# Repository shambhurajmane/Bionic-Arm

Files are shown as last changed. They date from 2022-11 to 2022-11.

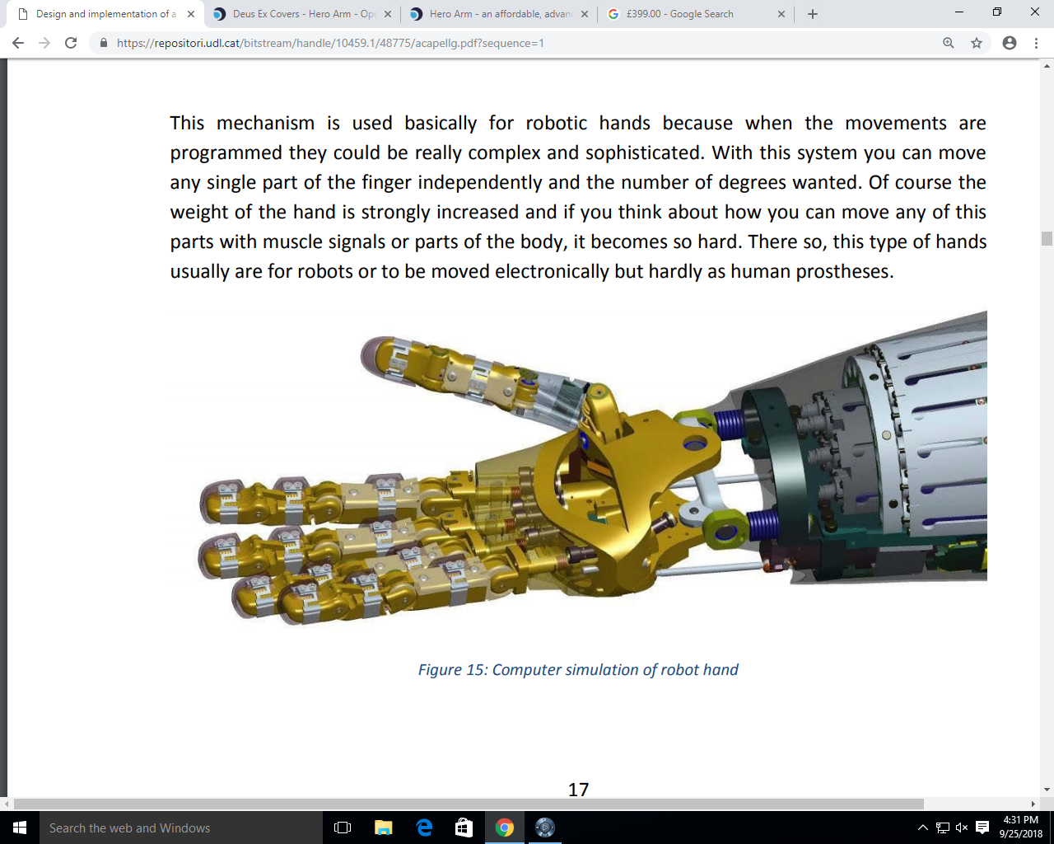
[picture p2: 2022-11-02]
Reference Doc/ARM1.png

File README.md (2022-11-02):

# Build and Control a Bionic Arm Using EMG Signals 

Brainwaves are the signals used by the human brain to communicate with the body. Most of the bionic arms designed and used in India are very costly yet they fail to provide the high Degree of Freedom. 
Due to less DOF, the movements of the arm are restricted to only a few actions like gripping. 

##  Objective of project 

-  To study the human-arm anatomy with reference to different gestures.
- To study the EMG signals related to lower arm/finger gestures.
- To acquire the EMG signals from a healthy person (one subject) and create datasets for various pre-decided gestures.
- To analyse the recorded signals and extract various features from them.
- To create a machine learning model that can identify these features.
- To apply the output of the machine learning model to the actuators in Bionic Arm to actuate the gestures.
- To design a low cost, high functionality (high Degrees of Freedom) Bionic Arm.
- To design a lightweight Bionic Arm using 3D print technology. 

We have succesfully built the Bionic Arm with 14 DOF.

git1

## Features

- Input:  EMG signal controlled bionic arm.
- 14 DoF bionic arm.
- Max weight is 656 gm for this we have used 3D printing technology.
- Fullscreen mode
- Machine learning model for classification of grasps.
- Total Power dissipated: 8W
- No of Hours the 2200mAh battery will last=(12*2200mAh)/8 W=3.3 hours.

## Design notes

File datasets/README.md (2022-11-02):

- The machine learning model is built to classify the gestures such as pinch , fist and relax.
- The dataset required for training and testing purpose was drawn from three EMG-sensors.
- These sensors are used to collect the data from three different regions of forearm.
- Sets of signal readings from three sensors are assigned to 'X' variable and gesture labbel is assigned to 'Y' variable.Then data was used for training and testing by the algorithm .The training dataset and testing dataset was in the ratio of 3:1.Accuracy of different classifiers such as KN Neighbours,Decision Tree,LINEAR DISCRIMINATION ANALYSIS, GAUSSIAN NB,LOGISTIC REGRESSION were tested against the dataset.Higher accuracy was obtained with Decision Tree.

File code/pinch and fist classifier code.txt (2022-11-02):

import pandas as pd
import matplotlib.pyplot as plt
import sklearn
from sklearn.model_selection import train_test_split
from sklearn import linear_model
from sklearn.utils import shuffle
from sklearn import preprocessing
import numpy as np

# PRE-PROCESSING OF DATA
file = pd.read_table('pinch and fist 8 december.txt')
feature_names = ['Sensor1', 'Sensor2', 'Sensor3']
X = file[feature_names]
y = file['grasp']

# remove nan error
import pandas as pd
X=X.replace([np.inf,-np.inf])
X = X.apply (pd.to_numeric, errors='coerce')
X = X.dropna()

y=y.replace([np.inf,-np.inf])
y = y.apply (pd.to_numeric, errors='coerce')
y = y.dropna()

# TESTING AND TRAINING
X_train, X_test, y_train, y_test = train_test_split(X, y, random_state=5)
from sklearn.preprocessing import MinMaxScaler
scaler = MinMaxScaler()
X_train = scaler.fit_transform(X_train)
X_test = scaler.transform(X_test)

# LOGISTIC REGRESSION
from sklearn.linear_model import LogisticRegression
logreg = LogisticRegression()
logreg.fit(X_train, y_train)
print('Accuracy of Logistic regression classifier on training set: {:.2f}'
     .format(logreg.score(X_train, y_train)))
print('Accuracy of Logistic regression classifier on test set: {:.2f}'
     .format(logreg.score(X_test, y_test)))

# DECISION TREE
from sklearn.tree import DecisionTreeClassifier
clf = DecisionTreeClassifier().fit(X_train, y_train)
print('Accuracy of Decision Tree classifier on training set: {:.2f}'
     .format(clf.score(X_train, y_train)))
print('Accuracy of Decision Tree classifier on test set: {:.2f}'
     .format(clf.score(X_test, y_test)))

# KN NEIGHBORS
from sklearn.neighbors import KNeighborsClassifier
knn = KNeighborsClassifier()
knn.fit(X_train, y_train)
print('Accuracy of K-NN classifier on training set: {:.2f}'
     .format(knn.score(X_train, y_train)))
print('Accuracy of K-NN classifier on test set: {:.2f}'
     .format(knn.score(X_test, y_test)))

#LINEAR DISCRIMINATION ANALYSIS
from sklearn.discriminant_analysis import LinearDiscriminantAnalysis
lda = LinearDiscriminantAnalysis()
lda.fit(X_train, y_train)
print('Accuracy of LDA classifier on training set: {:.2f}'
     .format(lda.score(X_train, y_train)))
print('Accuracy of LDA classifier on test set: {:.2f}'
     .format(lda.score(X_test, y_test)))

# GAUSSIAN NB
from sklearn.naive_bayes import GaussianNB
gnb = GaussianNB()
gnb.fit(X_train, y_train)
print('Accuracy of GNB classifier on training set: {:.2f}'
     .format(gnb.score(X_train, y_train)))
print('Accuracy of GNB classifier on test set: {:.2f}'
     .format(gnb.score(X_test, y_test)))

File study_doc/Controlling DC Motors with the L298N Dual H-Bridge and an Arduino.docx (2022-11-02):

Literature review

Development Boards

Development board is basically a printed circuit board with circuitry and hardware on-board to facilitate experimentation with certain microcontrollers. These boards can save you from a lot of repetitive tasks.

1. Arduino Development Board: ...
2. Raspberry Pi Development Board: ...
3. The BeagleBone Black Development Board: ...
4. The Intel Galileo Development Board: ...
5. The pcDuino Development Board:
6. The Uruk Development Board: ...
7. The Goldilocks Development Board: ...
8. The ExtraCore Development Board:
9. DIY Printed Circuit (PCB) Boards:

Arduino Development Board:

Arduino is the popular open-source electronics prototyping stage focused around simple to-utilize equipment and software. It's proposed for specialists, designers, and anybody intrigued by making intelligent articles or situations and is intended to be as adaptable as would be prudent to fit your venture's necessities. The Arduino Development Board is a good example of top development boards for DIY projects. Arduino is a company that deals with open source computer hard ware and software. The company designs and does manufacturing of kits creating digital devices and many interactive objects which have the capability of sensing and making good control of the whole physical world. Since it is an example of a microcontroller, it works swiftly and steadily. It is manufactured primarily by Smart Projects in Italy and many other countries and vendors.

# ARDUINO MEGA 2560 REV3

The MEGA 2560 is designed for more complex projects. With 54 digital I/O pins, 16 analog inputs and a larger space for your sketch it is the recommended board for 3D printers and robotics projects. This gives your projects plenty of room and opportunities.

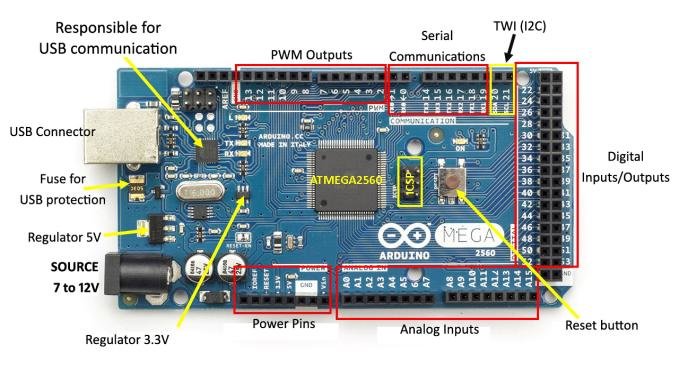
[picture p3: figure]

Controlling of servo actuation

### H-Bridge

Now that you know how DC motors work, how you can reverse their direction by changing polarity and how you can change their speed using pulse width modulation, let’s examine an easy way to do this using a very common circuit configuration called an “H-Bridge”.

An “H-Bridge” is simply an arrangement of switching the polarity of the voltage applied to a DC motor, thus controlling its direction of rotation. To visualize how this all works I’ll use some switches, although in real life an H-Bridge is usually built using transistors. Using transistors also allows you to control the motor speed with PWM, as described above.

In the first diagram we can see four switches which are all in the open or “off” position. In the center of the circuit is a DC motor. If you look at the circuit as it is drawn here you can distinctly see a letter “H”, with the motor attached in the center or “bridge” section – thus the term “H-Bridge”.

If we close (i.e. turn on) two of the switches you can see how the voltage is applied to the motor, causing it to turn clockwise.

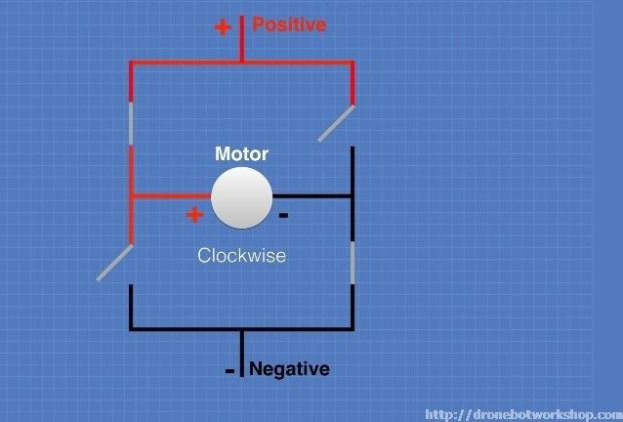
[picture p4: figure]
H-Bridge Clockwise
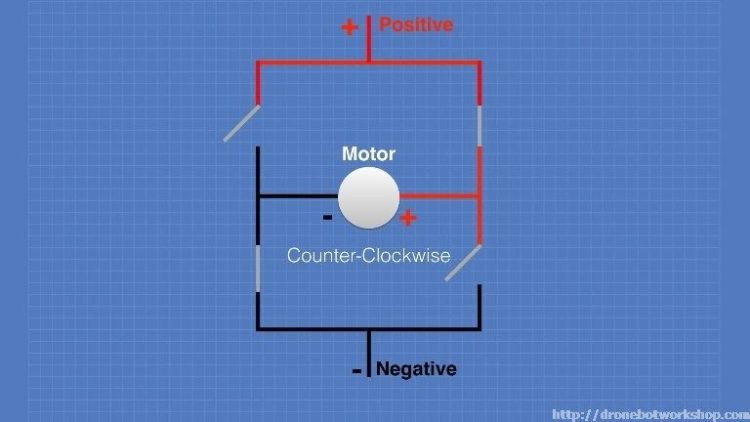
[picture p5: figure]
H-Bridge Counter-Clockwise
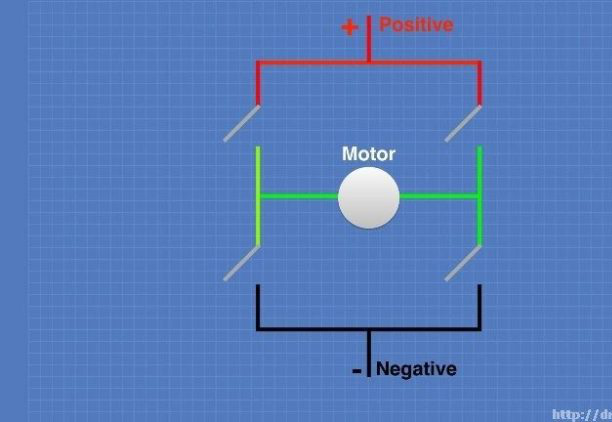
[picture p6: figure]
H-Bridge Configuration

Now we’ll open those switches and close the other two. As you can see this causes the polarity of the voltage applied to the motor to be reversed, resulting in our motor spinning counterclockwise.

This is pretty simple but effective. In fact if all you need to do is design a circuit to drive the motor full-speed in either direction you could actually build this as shown here, using a 4PDT (4 Pole Double-Throw) center-off switch. But of course we want to control the motor using an Arduino, so an electronic circuit where the switches are replaced by transistors is what we need.

### 1) L298N Module Pinouts

You’ll find a few different styles of L298N boards but they all operate in the same fashion. The board contains an L298N mounted on a heatsink, a 5 volt voltage regulator to “optionally) provide power for logic circuits, supporting diodes and capacitors and connectors as follows:

- Logic inputs for each H-Bridge circuit
- Power supply inputs for the motor power supply
- An optional 5 Volt power input for the logic circuits.
- Outputs for each DC motor

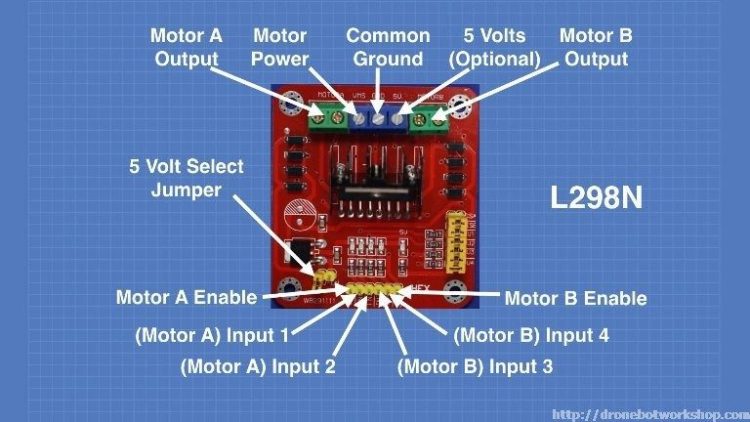
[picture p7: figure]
L298 Motor Control Module

A typical L298N Board is shown here.

You’ll notice that the board also has a number of jumpers. Most of the time you will leave them in place, with the exception of one. They are as follows:

- CSA – This is the “current sensing” function for Motor A. If the jumper is in this function is ignored. Most of the time you’ll leave this jumper in place.
- CSB – The “current sensing” function for Motor B. Again you’ll usually just leave this in place to disable this function.
- U1 – Input 1 pull-up resistor. You will usually leave this in place, which enables a 10k pull-up resistor for the input.
- U2 – Input 2 pull-up resistor.
- U3 – Input 3 pull-up resistor.
- U4 – Input 4 pull-up resistor.
- 5v-EN – This is the only jumper that you need to really pay attention to. When this jumper is in place it enables the boards internal 78M05 5 Volt regulator, supplying logic power from the motor power supply. When this jumper is enabled you will NOT supply 5 volts to the 5 Volt input terminal. When the jumper is removed you will need to supply 5 Volts to the 5 Volt input terminal.

If you do use the internal voltage regulator you’ll have to supply the motor power supply with at least 7.5 volts.

Speaking of the motor power supply it needs to be a bit higher voltage than the actual motor requirements. This is due to the internal voltage drop in the transistors that form the H-Bridge circuit. The combined voltage drop is 1.4 volts, so if you are using 6 Volt motors you’ll need to give the board 7.4 volts, if you have 12 volt motors then your motor supply voltage will need to be 13.4 volts.

The board has four input terminals plus two enable terminals. You will use these terminals to control both direction and speed or each motor. They are as follows:

- IN1 – Input 1 for Motor A
- IN2 – Input 2 for Motor A
- IN3 – Input 3 for Motor B
- IN4 – Input 4 for Motor B
- EN1 – Enable line for Motor A
- EN2 – Enable Line for Motor B

In order to simplify things a bit I’ll just discuss the inputs and enable for Motor A, Motor B functions identically.

The two Input lines control the direction that the motor rotates. I will call one direction “forward” and the other one “reverse”, if it makes more sense to you just substitute “clockwise” and “counterclockwise”.

You control motor direction by applying either a Logic 1 (5 Volts) or Logic 0 (Ground) to the inputs. This chart illustrates how this is done.

INPUT 1 | INPUT 2 | DIRECTION
Ground (0) | Ground (0) | Motor Off
5 Volts (1) | Ground (0) | Forward
Ground (0) | 5 Volts (1) | Reverse
5 Volts (1) | 5 Volts (1) | Not Used

As you can see only two combinations are actually used to control the direction of the motors rotation.

The Enable line can be used to turn the motor on, to turn it off and to control its speed. When the Enable line is at 5 Volts (1) the motor will be on. Grounding the Enable line (0) will turn the motor off.

To control the speed of the motor you apply a Pulse Width Modulation (PWM) signal to the Enable line. The shorter the pulse width, the slower the motor will spin.

2) MD10C

1.0 Introduction:

Enhanced 10Amp DC Motor Driver (MD10C) (http://cytron.com.my/p-md10c)is an enhanced version of the MD10B which is designed to drive high current brushed DC motor up to 13A continuously (for Rev2.0). It offers several enhancements over the MD10B such as support for both locked anti-phase and sign-magnitude PWM signal as well as using full solid state components which result in faster response time and eliminate the wear and tear of the mechanical relay.

Arduino main boards such as Arduino Uno (http://cytron.com.my/p-arduino-uno) are quite popular these days due to its easy-to-use programming environment. Therefore, by interfacing Arduino main board with MD10C, we gain easier control of DC motors. In addition, further adding an Arduino LCD Keypad Shield can help us to control the DC motor that connected to MD10C with the 6 momentary push buttons (built-in push buttons on LCD keypad shield including 1 Reset button) and also display some useful message or information.

In this tutorial, I am going to show several simple ways to drive DC brush motor using MD10C and Arduino.

How does MD10C work?

One of the features of MD10C is it supports both sign-magnitude and locked anti-phase PWM signal, means you can control motor in 2 different ways!

- Sign-magnitude mode You require 2 separate signals to control the motor, one is for direction (counterclockwise or clockwise) and another is for the speed. To control motor direction, DIR pin is connected to HIGH or LOW for different direction, whereas PWM pin is fed with PWM signal to control the motor speed.
- Locked anti-phase mode In this mode, only 1 signal is required to control both speed and direction of motor. PWM pin of MD10C is always connected to HIGH (5V), while DIR pin is fed with d to PWM signal. The direction of motor depends on whether the duty cycle of PWM signal is less than or more than 50%. The motor will run in one direction if the duty cycle is less than 50% and another direction if more than 50%. The motor stops if duty cycle is 50% (approximately). The speed depends on the percentage of duty cycle.

Sign-magnitude VS Locked anti-phase

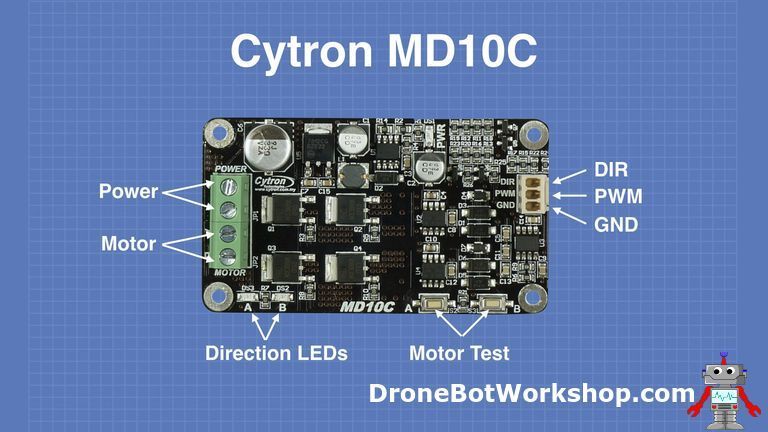
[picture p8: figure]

Main advantage of using locked anti-phase mode compare to sign-magnitude mode in motor controlling is it reduces number of I/O pins used since it uses only 1 signal for controlling both the speed and direction of motor. However, if locked anti-phase is used, in the beginning motor will run at maximum speed (as you can see in the video) when there is no PWM signal. Users will have to provide PWM signal at 50% duty cycle to DIR pin or set PWM pin (MD10C) to LOW state in the beginning. In terms of programming, the algorithm will be more complex because in locked anti-phase mode, motor speed changes with increment or decrement of PWM value depends on the direction which the motor is at. Motor becomes slower with increment of duty cycle if duty cycle of PWM signal is less than 50% or otherwise if duty cycle is more than 50%.

3) Md10a

Introduction

MDD10A (http://cytron.com.my/p-md10c) stands for Motor Driver Dual Channel 10(Amps). This DRIVER is the dual channel version of MD10C (http://cytron.com.my/p-md10c) which is designed to drive 2 brushed DC motors at high current s up to 10A each, continuously. Just like MD10C (http://cytron.com.my/p-md10c), MDD10A (http://cytron.com.my/p-md10c) also supports locked-antiphase and sign-magnitude PWM control. It uses all solid state components resulting in faster response times and eliminates the wear and tear of mechanical relays.

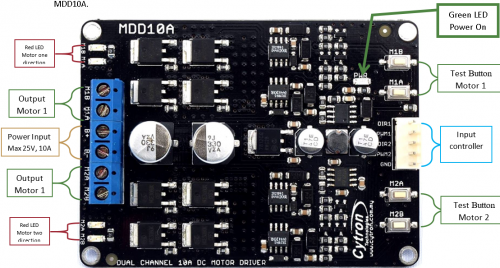
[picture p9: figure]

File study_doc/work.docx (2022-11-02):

work

### Why Arduino?

Thanks to its simple and accessible user experience, Arduino has been used in thousands of different projects and applications. The Arduino software is easy-to-use for beginners, yet flexible enough for advanced users. It runs on Mac, Windows, and Linux. Teachers and students use it to build low cost scientific instruments, to prove chemistry and physics principles, or to get started with programming and robotics. Designers and architects build interactive prototypes, musicians and artists use it for installations and to experiment with new musical instruments. Makers, of course, use it to build many of the projects exhibited at the Maker Faire, for example. Arduino is a key tool to learn new things. Anyone - children, hobbyists, artists, programmers - can start tinkering just following the step by step instructions of a kit, or sharing ideas online with other members of the Arduino community.

There are many other microcontrollers and microcontroller platforms available for physical computing. Parallax Basic Stamp, Netmedia's BX-24, Phidgets, MIT's Handyboard, and many others offer similar functionality. All of these tools take the messy details of microcontroller programming and wrap it up in an easy-to-use package. Arduino also simplifies the process of working with microcontrollers, but it offers some advantage for teachers, students, and interested amateurs over other systems:

- Inexpensive - Arduino boards are relatively inexpensive compared to other microcontroller platforms. The least expensive version of the Arduino module can be assembled by hand, and even the pre-assembled Arduino modules cost less than $50
- Cross-platform - The Arduino Software (IDE) runs on Windows, Macintosh OSX, and Linux operating systems. Most microcontroller systems are limited to Windows.
- Simple, clear programming environment - The Arduino Software (IDE) is easy-to-use for beginners, yet flexible enough for advanced users to take advantage of as well. For teachers, it's conveniently based on the Processing programming environment, so students learning to program in that environment will be familiar with how the Arduino IDE works.
- Open source and extensible software - The Arduino software is published as open source tools, available for extension by experienced programmers. The language can be expanded through C++ libraries, and people wanting to understand the technical details can make the leap from Arduino to the AVR C programming language on which it's based. Similarly, you can add AVR-C code directly into your Arduino programs if you want to.
- Open source and extensible hardware - The plans of the Arduino boards are published under a Creative Commons license, so experienced circuit designers can make their own version of the module, extending it and improving it. Even relatively inexperienced users can build the breadboard version of the module (https://www.arduino.cc/en/Main/Standalone) in order to understand how it works and save money.

# why ARDUINO MEGA 2560 REV3

The MEGA 2560 is designed for more complex projects. With 54 digital I/O pins, 16 analog inputs and a larger space for your sketch it is the recommended board for 3D printers and robotics projects. This gives your projects plenty of room and opportunities.

The Arduino Mega 2560 is a microcontroller board based on the ATmega2560 (http://www.atmel.com/Images/Atmel-2549-8-bit-AVR-Microcontroller-ATmega640-1280-1281-2560-2561_datasheet.pdf). It has 54 digital input/output pins (of which 15 can be used as PWM outputs), 16 analog inputs, 4 UARTs (hardware serial ports), a 16 MHz crystal oscillator, a USB connection, a power jack, an ICSP header, and a reset button. It contains everything needed to support the microcontroller; simply connect it to a computer with a USB cable or power it with a AC-to-DC adapter or battery to get started. The Mega 2560 board is compatible with most shields designed for the Uno and the former boards Duemilanove or Diecimila.

### Pulse Width Modulation (PWM)

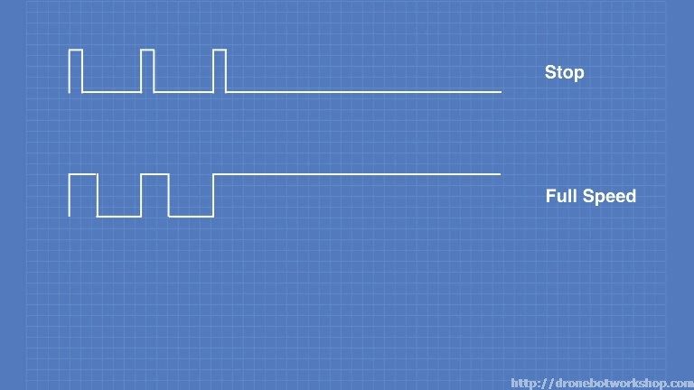
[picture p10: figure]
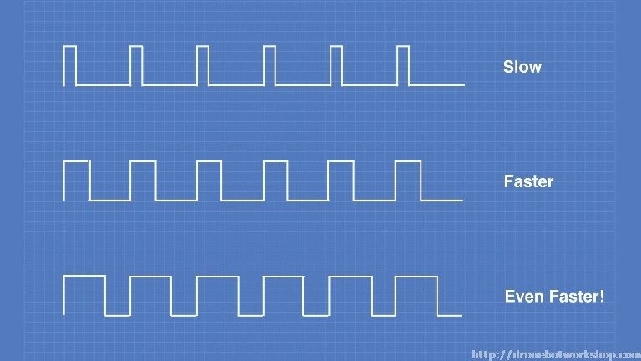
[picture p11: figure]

A far better method of controlling DC motors is to use pulse width modulation or PWM. If you’ve read up on controlling LED’s with your microcontroller you probably have already run into PWM as it’s also a good method of controlling the brightness of an LED.

With PWM the motor is sent a series of pulses. Each pulse is of the full voltage that the motor can handle so a 6-volt motor will be sent 6 volt pulses while a 12-volt motor will be sent 12 volt pulses. The width of the pulses are varied to control the motor speed, pulses with a narrow width will cause the motor to spin quite slowly. Increasing the pulse width will increase the speed of the motor, as illustrated below.

In order to stop the motor completely you just stop pulsing it, essentially sending it zero volts. To run it at full speed you send it the full voltage, again without pulsing it.

You can build a simple PWM generator using a 555 timer and discrete components but it’s a lot easier to use an Arduino. The Arduino has a function called “analogWrite” which is used to drive any of its PWM-capable outputs (the Arduino Uno has 6 digital outputs that are also capable of PWM).

Miniature Linear Motion actuation ·

PQ12 Actuonix Motion Devices unique line of Miniature Linear Actuators enables a new generation of motion-enabled product designs, with capabilities that have never before been combined in a device of this size. These tiny linear actuators are a superior alternative to designing your own push/pull mechanisms. Their low cost and easy availability make them attractive to hobbyists and OEM designers alike. The PQ12 actuators are complete, self contained linear motion devices with position feedback for sophisticated position control capabilities, or end of stroke limit switches for simple two position automation.

PQ12 Controller Options

Option P – Potentiometer Position Feedback WIRING: (see next page for pin numbering)

1 – Feedback Potentiometer negative reference rail

2 – Actuator Motor Power

3 – Actuator Motor Power

4 – Feedback Potentiometer positive reference rail

5 – Feedback Potentiometer wiper

The –P actuators have no built in controller, but do provide analog position feedback. While voltage is applied to the motor power pins (2 & 3) the actuator extends. Reverse the polarity and the actuator retracts. Position of the actuator stroke can be monitored using the internal linear potentiometer. Provide any stable low and high reference voltage on pins 1 & 4, then read the position signal on pin 5. The voltage on pin 5 will vary linearly between the two reference voltages in proportion to the position of the actuator stroke. Connect to an LAC board for easy interface with any of the following control signals: Analog 0-5V or 4- 20mA, or Digital 0-5V PWM, 1-2ms Standard RC, or USB.

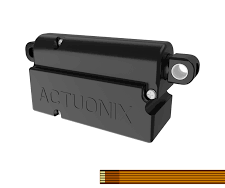
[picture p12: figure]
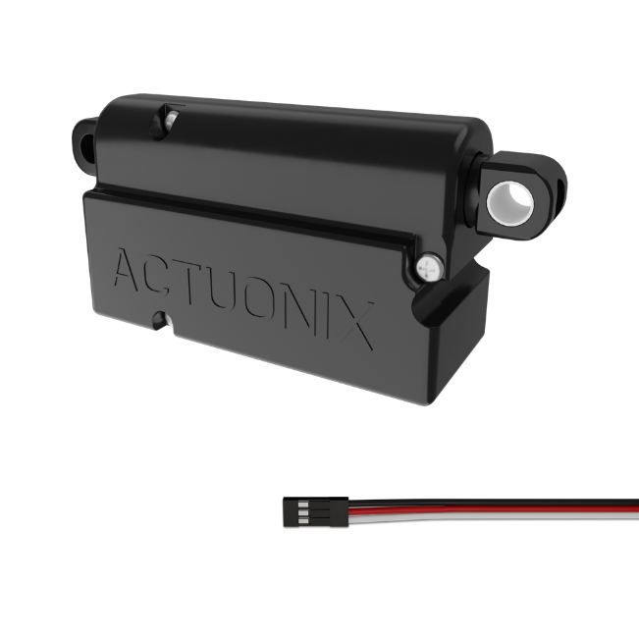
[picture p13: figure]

Option P option

Option R – RC Linear Servo WIRING:

1 - RC input signal (RC-servo compatible)

2 - Power (+6 VDC)

3 - Ground

The –R actuators or ‘linear servos’ are a direct replacement for regular radio controlled hobby servos. The desired actuator position is input to the actuator on lead 1 as a positive 5 Volt pulse width signal. A 2.0 ms pulse commands the controller to fully retract the actuator, and a 1.0 ms pulse signals it to fully extend. If the motion of the actuator, or of other servos in your system, seems erratic, place a 1–4Ω resistor in series with the actuator’s red V+ lead wire. The PQ12–R Linear Servos are designed to work with typical RC receivers and battery packs. Consequently, they also are compatible with Arduino control boards, VEX Microcontrollers and many other similar boards designed for robotics.

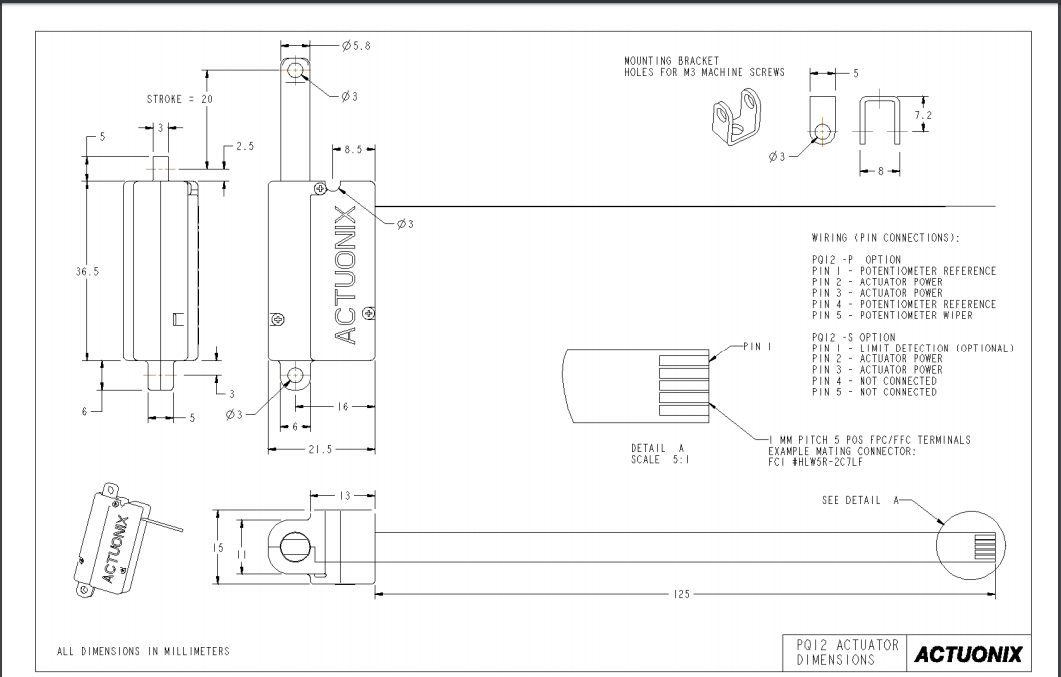
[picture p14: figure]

Actuator dimensioning and wiring diagram

Description of MG995 :

Getting an original TowerPro Servo Motor is not an economical option at all!!! And is also a very difficult task to recognize and buy an original TowerPro servo, Because there are many suppliers spread over different online shops who are selling fake servo motors under this Brand name. Robu.in believes in satisfied customers, so whatever the product is we first import them then test them for their supplier defined and standard capabilities. Only after doing all the possible quality checks we make the product available to our customers.

We have imported this copy of original TowerPro MG995 High-Speed Servo from our trusted supplier. Though the motor is the copy of the original High-Speed TowerPro MG995 servo, it is compatible with all the applications that use the genuine TowerPro MG995 Metal Gear Servo Motor because of its same size, comparable quality, and optimized performance. It has metal gears which makes it robust and reliable motors. These TowerPro MG995 Metal Gear Servo Motors are the high-speed servo motors with the mighty torque of 10 kg/cm.

The optimized performance and reliability of this servo have made it the favorite choice of many RC hobbyists. The TowerPro MG995 High-Speed Digital Servo Motor rotates 90° in each direction making it 180° servo motor. It is a Digital Servo Motor which receives and processes PWM signal faster and better. It equips sophisticated internal circuitry that provides good torque, holding power, and faster updates in response to external forces. They are packed within a tight sturdy plastic case which makes them water and dust resistant which is a very useful feature in RC planes, Boats, and RC Monster Trucks etc. It equips 3-wire JR servo plug which is compatible with Futaba connectors too.

Wire Description

RED – Positive

Brown – Negative

Orange – Signal

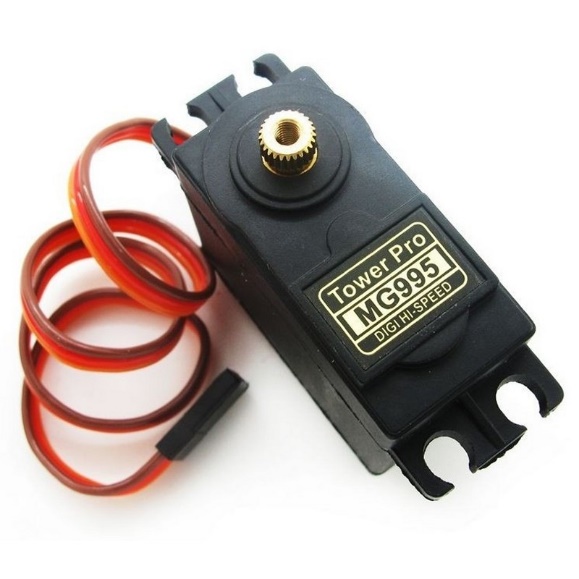
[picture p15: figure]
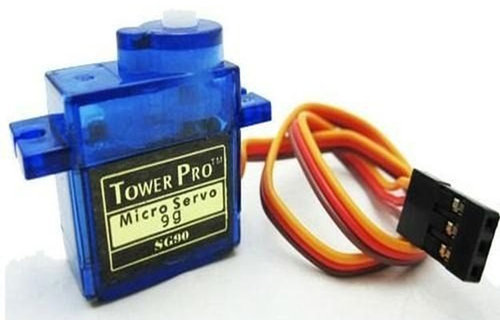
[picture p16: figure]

# Overview of fsr

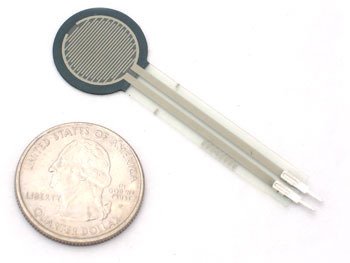
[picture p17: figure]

FSRs are sensors that allow you to detect physical pressure, squeezing and weight. They are simple to use and low cost. This is a photo of an FSR, specifically the Interlink 402 model. The 1/2" diameter round part is the sensitive bit.

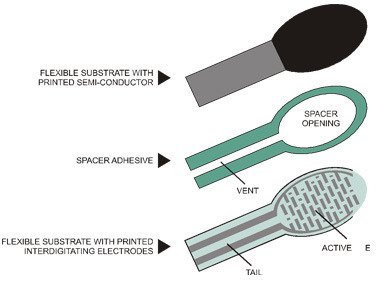
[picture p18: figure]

The FSR is made of 2 layers separated by a spacer. The more one presses, the more of those Active Element dots touch the semiconductor and that makes the resistance go down.

FSRs are basically a resistor that changes its resistive value (in ohms Ω) depending on how much it is pressed. These sensors are fairly low cost, and easy to use but they're rarely accurate. They also vary some from sensor to sensor perhaps 10%. So basically when you use FSRs you should only expect to get ranges of response. While FSRs can detect weight, they're a bad choice for detecting exactly how many pounds of weight are on them.

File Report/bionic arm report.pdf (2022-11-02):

## A Project Stage-I Report on

# BIONIC ARM

By

Mr. Shambhuraj Anil Mane.

Mr. Sukrut Sanjay Bhujbal.

Ms. Namrata Nitin Potnis.

## Guide

Prof. Akshay C Kulkarni.

# Department of Mechanical Engineering

# Pune Vidyarthi Griha’s College of Engineering

and Technology.

[2018-19]

# Pune Vidyarthi Griha’s College of Engineering

and Technology, Pune.

# C E R T I F I C A T E

This is to certify that Mr. Shambhuraj Anil Mane, Mr. Sukrut Sanjay Bhujbal and Ms. Namrata Nitin Potnis, has successfully completed the Project Stage – I entitled “Bionic Arm” under my supervision, in the partial fulfilment of Bachelor of Engineering -Mechanical Engineering of University of Pune.

Date:

Place:

Prof. Akshay C Kulkarni.

Guide | Internal Examiner
Dr. Shivaji V Gawali. | Dr. Yogesh P Nerkar.
Head of the Department | Principal

## ACKNOWLEDGEMENT

The success and final outcome of this project requires a lot of guidance and assistance from

many people and we are extremely privileged to have got all of this while working on the

project. All that we have done is only due to such supervision and assistance and we would

not forget to thank them.

We owe our deep gratitude to our project guide Prof. A.C. kulkarni who took keen interest

on our project work and guided by providing all the necessary information for developing a

good mechanical design.

We would further like to extend our gratitude towards PI Lab who provided us with all the

resources for executing the steps needed for the project. We would also like to thank our

Prof. Dr. S. V. Gawali, Head of the Department for giving us the opportunity to work on this

project.

We are also thankful to all teaching and non-teaching staff members of Mechanical

Engineering of PVG’s College of Engineering and Technology, Pune for their valuable time,

support, comments, suggestions and persuasions.

Shambhuraj mane

Sukrut Bhujbal
Namrata potnis

# CONTENTS

Chapte r No. | Topic | Page No.
1. | INTRODUCTION | 2
| 1.1 INTRODUCTION TO EMG | SIGNALS | 2
| 1.2 | MOTIVATION | 2
| 1.3 | OBJECTIVE | 2
| 1.4 SOCIAL RELEVANCE OF THE | PROJECT | 3
2. | LITERATURE REVIEW | | 4
2.1 | BIONIC ARM DESIGN | 4
| | 2.1.1 | INTRODUCTION | 4
| | 2.1.2 | PROSTHETIC ARM | 4
| | 2.1.3 | ANATOMY OF HUMAN HAND | 5
| | 2.1.4 ROBOTIC APPROACH TO HUMAN | HAND | 6
| | 2.1.5 | GRASPS | 7
| | 2.1.6 | COMPARATIVE ANALYSIS | 8

| 2.2 | WRIST DESIGN | 9
| | 2.2.1 | INTRODUCTION | 9
| | 2.2.2 | ARTICULATION METHOD | 10
| | 2.2.3 | JOINT TYPES | 11
| | 2.2.4 | MECHANISM TYPE | 12
| | 2.2.5 | COMMON ISSUE WITH WRIST | 12
| 2.3 | ACTUATORS | | 12
| 2.4 | REVIEW ON TACTILE SENSOR | | 13
| 2.5 | DEVELOPMENT BOARDS | | 15
3 | METHODOLOGY | | | 22
| 3.1 | MECHANISM SELECTION | | 22
| 3.2 | MOTOR SELECTION | | 22
| | 3.2.1 | SELECTION PROCEDURE | 22
| | 3.2.2 | MOTOR SIZING CALCULATION | 23
| | 3.2.3 | TORQUE | 24

| | 3.2.4 | LOAD TORQUE | 24
| | 3.2.5 | STALL TORQUE CALCULATIONS | 25
| 3.3 | CAD MODELLING | | 28
| | 3.3.1 | OUTLINE | 28
| | 3.3.2 | CAD MODELLING | 28
| 3.4 | ACTUATION OF WRIST | | 32
| | 3.4.1 | WHY ARDUINO? | 32
| | 3.4.2 | PULSE WIDTH MODULATION | 33
| | 3.4.3 | MINIATURE LINEAR MOTION ACTUATION | 34
| | 3.4.4 | DESCRIPTION OF MG 995 | 36
4 | | EXPERIMWNTAL VALIDATION | | 39
| 4.1 | ACTUATOR 3 PIN AND 5 PIN | | 39
| 4.2 SERVO MG995 MICRO SERVO AND METAL | GEAR SERVO | | 40
| 4.3 | FORCE SENSORS | | 41
5 | | FUTURE SCOPE | | 42
| 5.1 FUTURE SCOPE FOR THE EMG SENSOR | DESIGN | | 42

| 5.2 FUTURE SCOPE FOR THE EMG SIGNAL | ANALYSIS AND CLASSIFICATION | 42
| 5.3 | FUTURE SCOPE FOR BIONIC ARM | 42
| 5.4 | FUTURE SCOPE FOR PROSTHETICS | 43
6 | REFERENCE | | 44

# List of figures

Sr. no | Topic | Page No.
1. | TYPES OF PROSTHETICS | 4
2. | ANATOMY OF HUMAN HAND | 5
3. | HIERARCHY O GRASPS | 7
4. PROSTHETI ARM | COMPARATIVE | 8
5. | MODULAR PROSTHETICS ARM | 9
6. | 3 DOF OF THE HEALTHY HUMAN WRIST | 10
7. TYPES OF MECHANICAL | JOINTS | 11
8. CONTROLLING OF SERVO | ACTUATION | 16
9. | H BRIDGE | 17
10. | L298N MODULE PINOUTS | 17
11. | CYTRON MD 10C | 21
12. | MD 10A | 21
13. | UNIVERSAL JOINT | 22

# 1.INTRODUCTION

1.1 Introduction to bionic arm
The human hand is a complex system, with a large number of degrees of freedom sensors

embedded in its structure, actuators and tendons, and a complex hierarchical control.

Despite this complexity, the efforts required to the user to carry out the different

movements are quite small. The myoelectric arm works under the influence of

Electromyography (EMG) signals extracted from skin surface. These Electromyographic

signals are utilized to run various motors which enable the user (patient) to grip and move

limbs in a much more effective manner. prosthetic hands are replication of the natural

hand, with significantly reduced grasping capabilities and no sensory information

delivered back to the user. Despite the significant impact of losing a hand, numbers of

amputees requiring prosthesis are too small to push manufacturers to innovate their

products, so both the control interfaces and mechanisms have barely changed in the past

40 years.

1.2 What are EMG signals

The Electromyogram signal is a neuro muscular signal that measures electric

potential generated in muscles during their contraction and relaxation representing

neuromuscular activities. The amplitude of the signal is in the range of 0-10 mV.

Signal frequency range is above 12 Hz. These signals can be recorded from the lower

elbow region of the arm for a certain set of gestures. These gestures can be rest, palm-

up, palm-down, fist, hold, etc. Various features like average, L2-norm, kurtosis,

skewness, etc. can be extracted from these recorded signals. With good analysis tools

and algorithms, the EMG signals can be mapped with the control signals for the

actuators in Bionic Arm with a high degree of accuracy.

1.3 Social relevance of the project

The outcome of this project is to create a cost effective less weight Bionic Arm that can

mimic the hand gestures correctly. This will help lower elbow amputees by providing

them a solution that will help them in their day to day tasks. This in turn will give them

more independence and improve their quality of life. The study of problems perceived by

the amputees was done. As our design is only specified for lower elbow amputees the

study was only limited to problems perceived by lower elbow amputees. Recently

development of myoelectric prostheses has mostly focused on increasing the number of

DoFs while increasing joint speed and torque. However, these devices achieve improved

dexterity at the cost of increased weight, size, and complexity. There is trade-off between

the dexterity of Bionic Arm and the weight, size of the Bionic Arm. In they have

suggested that the weight of Bionic Arm should be around 500 grams.

R.F Weir et al consulted different amputees and has proposed following rules of thumb for

design of prosthetic arm-

1. The total weight of prosthesis should be around 500 grams. A lighter prosthetic arm is

always beneficial for amputees as they can easily use the device for carrying out daily

activities without any hardships.

2. The Bionic Arms should incorporate main functional grasps like Power Grasp, Pinch

Grasp and Lateral Grasp.

3. The design and control of Bionic Arm should be compliant enough.
4. Simple and robust finger kinematic design should be implemented.
5. The exact need of amputees should be mapped and then specified design for that person should be initiated. This approach gives a better design output which will be definitely compliant to the amputee

1.4 Objective of project

1. To study the human-arm anatomy with reference to different gestures.
2. To study the EMG signals related to lower arm/finger gestures.
3. To acquire the EMG signals from a healthy person (one subject) and create datasets for

various pre-decided gestures.

4. To analyse the recorded signals and extract various features from them.
5. To create a machine learning model that can identify these features.
6. To apply the output of the machine learning model to the actuators in Bionic Arm to actuate

the gestures.

7. To design a low cost, high functionality (high Degrees of Freedom) Bionic Arm.
8. To design a lightweight Bionic Arm using 3D print technology.

# 2.LITERATURE SURVEY

### 2.1 Introduction

Prosthesis and orthotics are clinical disciplines that deal with artificial limbs(prostheses) for

people with amputation and people with muscoskeletal weakness. Bionics is a field of

engineering which is inspired from biology. Bionic Arm is by-product of prosthetics and

Bionics whose aim is to provide an artificial arm for amputees. Thus, this artificial robotic

prosthetic arm provides amputees with artificial hand which can help them to carry out daily

activities as efficiently as they used to carry out when they had their biological hand intact to

their body. The following literature survey consist of study of designing and building of Bionic

Arm.

### 2.2 Prosthetic Arms

The hand is a powerful tool and its loss causes a severe psychological and physical drawback.

Despite the significant impact of losing a hand, numbers of amputees requiring a prosthesis are

too small to push manufacturers to innovate their products, so both the control interfaces and

mechanisms have barely changed in the past 40 years. The most technologically advanced

prostheses are myoelectric ones; one or two DoFs, motorized hands (or hooks) are activated by

antagonist residual muscle contractions where the EMG signal is picked-up by surface

electrodes in the prosthetic socket and processed to functionally open and close the palm (or

pronate/supinate the wrist).

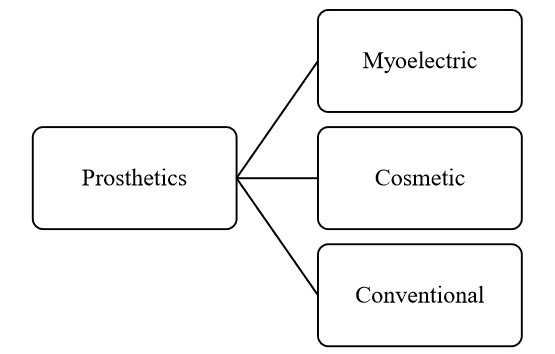
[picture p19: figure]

Figure 1: Types of prosthetics

Before learning to build highly functional, high DoF and light weight prosthetic arm study of

human hand, its working, number of joints, tendon muscle relationship, etc. is needed.

### 2.3 Anatomy of Human Hand

The human hand consists of 4 fingers and a thumb and is the main organ for physical interaction

with the environment surrounding the human body. A schematic of the bones in the human

hand can be seen in Figure below.

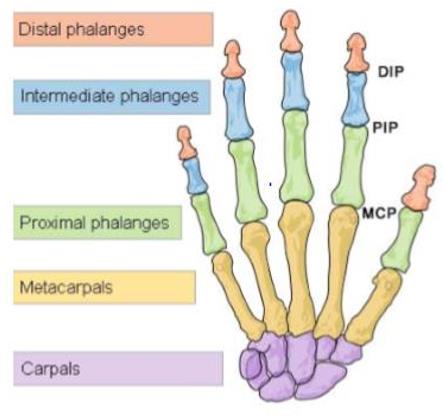
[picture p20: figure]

Figure 2: Anatomy of Human hand

Every finger has 3 joints, which are-

- DIP (Distal Interphalangeal Joint)
- PIP (Proximal Interphalangeal Joint)
- MCP (Metacarpal Phalangeal Joint)

Fingers are divided in different segments connected by joints called as Phalanx, following are

different phalanxes -

### 2.3.1 Metacarpal Phalanx

The metacarpal phalanx (yellow) is connected to the first finger segment (proximal phalanx)

with a joint called the metacarpophalangeal joint (MCP-joint). The MCP-joint is able to

perform to types of movement, flexion/extension and abduction/adduction. Flexion in this case means bending the finger while extension means extending the finger. Abduction denotes the

sideways motion of the finger away from the midline of the hand. The opposite movement,

adduction, means moving the finger back against the midline of the hand.

### 2.3.2 Proximal Phalanx

The proximal phalanx (green) is connected to the metacarpal phalanx through the MCP-joint.

On the other side of the finger segment it is connected to the second finger segment

(intermediate phalanx) with a joint called the proximal interphalangeal joint (PIP joint). The

PIP-joint only has one axis of motion and is therefore called a hinge joint. Flexion and

extension of the PIP-joint means bending and stretching the first finger joint.

### 2.3.3 Intermediate and Distal Phalanx

The intermediate (blue) and distal (red) phalanges are the middle and outer segments of the

finger, respectively. They are connected with the distal interphalangeal joint (DIP joint) which

is a hinge joint like the PIP-joint.

### 2.4 Robotic approach to the human hand

There are several aspects of the human hand that makes it very hard to imitate in a robotic

application. First of all, the human hand has a very complex kinematic model. The fingers alone

possess 21 DoFs. In addition to the finger, movement of the palm includes 6 DoF, 27 for the

whole hand. The movement of the palm itself is rarely seen in robotic hands; a solid palm is

often used instead. In addition to the high degree of freedom, the finger is also very sensitive

to external input. To imitate all the nerves on the surface of the finger is very complicated.

Normally, a number of touch sensors are seen instead. Thus, mimicking human hand’s

functionality in prosthetic arm is a difficult task and a great amount of research is undertaken

to create an anthropomorphic prosthetic arm.

To implement high functionality anthropomorphic prosthetic hand which will be controlled by

myoelectric signals or EMG signals, efficient and light weight actuators are needed.

### 2.5 Grasps

For designing an artificial human hand there is need to study the human arm and its

functionality. Human hand carries out different grasps to pick and handle different objects in

our daily life. Thus, for designing purpose of Bionic Arm, study of different grasps was done.

The Cutkosky grasp taxonomy was referred. Mark Cutkosky wrote a paper in 1989 where he

classified a set of manufacturing grasps in order to evaluate analytical models of grasping and

manipulation with robotic hands. This taxonomy is widely used by robotic scientists and

engineers who undertake designing of robotic arm. The following image is the hierarchical tree

of grasps referred from Mark Cutkosky’s paper-

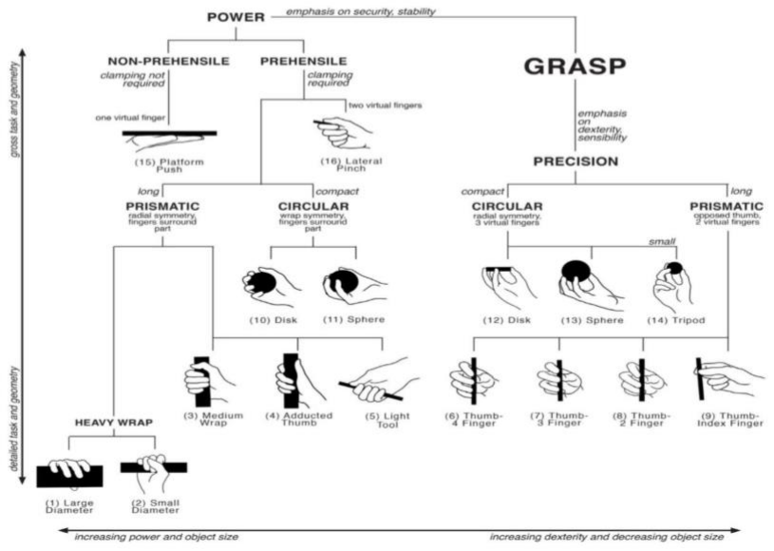
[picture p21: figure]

Figure 3: Hierarchy of grasps

Following is the list of important grasps studied and their use in everyday life-

- POWER GRASP- for picking heavy weights.
- PRECISION GRASP- for picking cherry from trees.
- LATERAL GRASP-for picking spoon laterally.
- INDEX Pointing for typing.
- Basic Gesture likes counting.

In Weir et al has made comparison analysis on different types of commercial Prosthesis and Bionic Arms designed by research institutes. Following Prosthetic arms were studied-

- Vincent hand by Vincent Systems.
- iLimb hand by Touch Bionics.
- BeBionic hand by RSL Steeper
- Michelangelo Hand.

### 2.6 Comparative Analysis

In general characteristics of commercial prosthetic hands is stated. Vincent Hand was

designed for 6 DoF and DC motor worm gear was used for actuation. Adaptive Grip

was the feature. BeBionic hand is the most successful commercial prosthetic arms

which used DC Motor Worm Gear for actuation method. Bebionic used carbon fiber

body which lead to reduction in weight. It only weights 465 gram. iLimb by touch

bionic is also successful commercial prosthetic arms which consists of features like Wi-

Fi control and adaptive grasps.

After studying these prosthetic arms, it is analyzed that all these companies used custom

made expensive actuators which increases the total cost of entire device. Though they

were light enough and had compliant actuation, they were very expensive which can’t

be afforded by middle-class and below middle-class people. Thus, work on cost

effective Bionic Arm is an undergoing research.

Modular Prosthetic Limbs

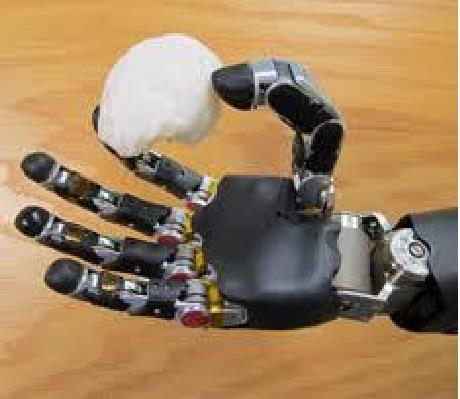
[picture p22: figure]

Figure 2-18: Modular Prosthetic Arm

Modular Prosthetic Limbs are till now the most advanced prosthetic arm designed by

researchers in John Hopkins University which was funded by DARPA. MPL is the most

advanced prosthetic limb which achieved intuitive feedforward control through EMG

sensor band and it also incorporated feature of natural sensory feedback to the user.

MPL is the most expensive Bionic Arm which is successfully tested on an amputee. It

incorporated more than 100 sensors on the Arm including force, contact and

temperature sensor. No doubt it is the most advanced artificial limb

### 2.7 Actuators

Following are common different types of actuators that can be used in prosthetics-

- Hydraulics- Hydraulics, a widely used form of general actuation is hydraulic

systems. A hydraulic system typically consists of a pump, a reservoir, a valve

and an actuator. Hydraulics are bulky and include oils which will make difficult

for amputee to use it as prosthetics.

- Pneumatics- In pneumatics, a pressurized gas is used to create actuation,

typically by filling a cylinder with air. Pneumatic valves and cylinders are

bulky so they cannot be used in prosthetic applications.

- Intelligent material used as actuator (Soft Robotics)- Intelligent material used

as actuator are not seen in common life, these include Shape Memory Polymers

(SMP) and Shape Memory Alloys (SMA). Some polymers change shape when subjected to voltage and thus due to shape change actuation is incorporated.

Shape memory alloys are also used similarly to actuate. Thus, such intelligent

material can be used in prosthetics for creating actuation at joints. Such

actuation method closely mimics the muscles of our finger and brings us close

to the goal of anthropomorphism. Advantages of such actuators is low cost and

simplicity. But such actuators incorporate joule heating effect for shape change

and actuation, such actuation mechanisms are not safe for prosthesis

application and it will require insulation. Moreover, high DoF and robustness

in prosthetics cannot be obtained using these actuators. We referred to, these

companies manufactured SMA and SMP. SMP technologies, Japan,

manufactured SMP material which had moulding point around 55 centigrade

but due to its exorbitant price it was hard to be affordable for the project. Thus,

intelligent material used as an actuator had to be dropped for this application.

- Electric actuators provide sufficient torque, force, robustness and flexibility

and are suitable for this application. Following are different electric actuators

that can be incorporated in prosthetic arms-

1. DC Motors
2. BLDC Motors
3. Servo Motors
4. Stepper Motors
5. Linear actuators

### 2.8 Review on Tactile Sensor

In tactile sensing technology has been reviewed. Tactile sensor or Force sensor detects

pressure or force applied on the surface of the sensor. It provides information related to

the interaction forces between object and fingers of robotic arm. Tactile sensor taken

in closed loop, helps in precise control of force applied on the object by the fingers of

robotic arm. Biological human hand also has many senses like the human hand can

detect hotness or coldness of the object, pressure applied on the finger and pain on the

finger.

Tactile sensors are incorporated by engineers and researchers working on prosthetic

arms and Bionic Arms, to have precise object handling and manipulation. Tactile

sensors help to control force imparted on the object. For Bionic Arm, having control on

force imparted on the object is important because an amputee interacts with different

types of objects like hammer, flower, eggs etc.

If the Bionic Arm applies same amount of force for holding hammer on holding an egg,

it will destroy the egg.

One axis and 3 axis tactile sensors are available in market. 3 axis tactile sensors are

used for calculating normal and tangential forces simultaneously, which also helps in

detecting slippage of object from the fingers. But the 3-axis tactile sensor are

expensive, so mostly people prefer to use single axis tactile sensor Thus, use of tactile

sensor in field of prosthetics is important.

Following are different types of tactile sensors –

I. Piezo resistive sensor.
II. | Capacitive sensors.
III. | Piezoelectric sensors.
IV. | Quantum Tunnel Eff ect Sensors.
V. Optical Tactile sensors.

Amongst these sensors, following is the description of piezo resistive sensor and

capacitive sensors-

I. Piezo resistive Sensor

Piezo resistive effect is a physical process during which electrical resistance changes

when the material is mechanically deformed. There are several technologies based on

piezoelectric sensors. Force Sensitive Resistor (FSR) is based on piezo resistive effect.

In FSR when the sensor is deformed, the resistance changes. The FSR voltage divider

configuration can be given as input to the analog to division converter of

microcontroller for calculation of force applied on the sensor.

FSR have advantages like low cost, flexible and simple to manufacture but it has many

disadvantages like it has less repeatability after multiple deformation. The sensitivity

of sensor also reduces due to wear and tear of the sensor. Thus, FSR are not accurate

solution for precise force measurement.

II. Capacitive Force Sensor

Capacitive sensors consist of two conductive plates separated by compressible

dielectric material. When force is applied on the object the gap between the plates

changes and capacitance is also changed. The change in capacitance is detected and

inferences are made for how much force is applied.

Capacitive sensor technology has several advantages over resistive, including greater

stability in terms of repeatability and durability, and can measure low levels of pressure with accuracy. Capacitive sensor gives linear output; it facilitates measurement of

proportional force.

Thus, capacitive sensor is more accurate than FSR and good for long term prototyping

in Bionic Arms.

### 2.9 Grasp Control

Bionic Arm helps amputees to live a normal life and become less dependent on others.

For amputees to carry out their daily activities, it is important for the Bionic Arm to

have firm grasping skills on different types of object as their principal feature. Thus,

having good grasping skills and improved dexterity leads to achieving the purpose of

an artificial human hand.

To achieve good grasp, it is important to devise grasping control algorithm or grasping

control mechanism.

To achieve a stable grasp following prerequisites should be followed:

To hold the object properly, minimum grip force should be applied. The minimum grip

depends on the weight and surface friction of the object trying to be lifted.

Grip force is naturally adjusted by human hands when it feels that object is slipping

from the hands. When an object slips, it generates vibrations which can be measured

and quantified. This is susceptible to noise, but is still viable with adequate filtering.

To hold heavy object maximum force should be applied. The maximum grip force

depends on the mechanics of the hand and the maximum force that can be applied by

the actuators/motors. Depending upon how much force can be applied by the Bionic

Arm, there must be a standard grip strength which cover range of scenarios. Haptic

feedback could play a role here. Firstly, by providing feedback in terms of pressure and

secondly by amplifying the vibrations caused by slipping. This approach allows to have

natural feedback to the amputees. Having these prerequisites followed leads to good

base for achieving stable grasp of the Bionic Arm on any object.

### 2.10 Wrist Design

The human wrist contributes greatly to hand mobility and manipulation capabilities in healthy

individuals, but both the commercial and research domains have often overlooked prosthetic

wrists in favour of terminal device development.

The healthy human wrist is capable of three degrees of freedom (DOF). These DOFs are

pronation/supination, flexion/extension, and radial/ulnar deviation (Figure). Radial/ulnar

deviation is sometimes called abduction/adduction (respectively), and pronation/supination

may be called wrist rotation. pronation/supination does not occur at the carpal bones of the

wrist, but actually occurs within the forearm, as the radius crosses over the ulna in a twisting

motion when moving from supinated to pronated positions. It should also be noted that motion

originating in the carpal bones (flexion/extension and radial/ulnar deviation) is coupled,

meaning that motion in one DOF limits motion in the other (e.g. the amount of radial deviation

is reduced when fully extended than from the neutral position).

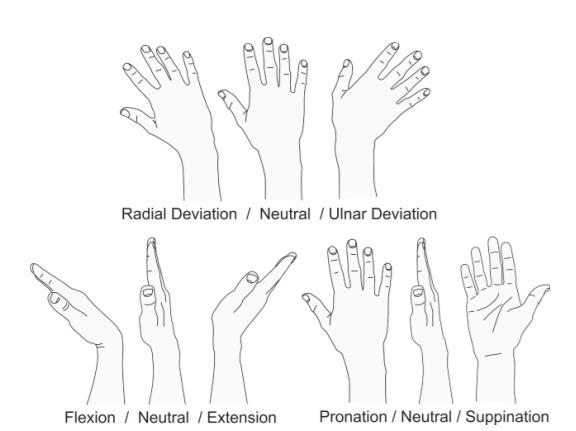
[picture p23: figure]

Fig 6 - Three degrees of freedom (DOF) of the healthy human wrist

For an unaffected human wrist, the maximal ranges of each DOF fall within the bounds of

76°/85°, 75°/75°, and 20°/45° for pronation/supination, flexion/extension, and radial/ulnar

deviation, respectively. Various groups have studied the range of motion (ROM) of the

various DOF of the human wrist while performing Activities of Daily Living (ADLs).

These investigations have generated a variety of ROM that fall within the bounds of

65°/77°, 50°/70°, 18°/40° for pronation/supination, flexion/extension, and radial/ulnar

deviation, respectively. Wrist pronation torque ranges from 6-10 Nm and flexion torque

ranges from 8-14 Nm.

### 2.10.1 Articulation Method

The function of a prosthetic wrist is to enable reorientation of a TD relative to the

forearm. Articulation is achieved via Passive, Body Powered, or Active methods. In a

passive wrist the user manually adjusts wrist and terminal device (TD) position, either

through their contralateral arm, body and/or environmental features. For example, a

terminal device may be clamped between the hip and table edge to enable re-

orientation. Body powered devices utilize motion and accompanying forces in other

parts of user’s body to achieve motion of a prosthetic device. The user typically wears

a shoulder harness with an attached Bowden cable to transmit force from the shoulder

to the prosthesis. Most commonly this is used to achieve opening/closing of a terminal

device, such as a Hosmer Hook, but body powered mechanisms have also been applied

to other prosthetic components. In active devices, an actuator, such as an electric motor,

is used to generate force and motion in the prosthesis. Such devices are typically part

of myoelectric systems. Note that a prosthetic device may have an actuator in it, but

will not be considered an active mechanism in this paper if the actuator does not exert

control over at least 1 DOF of the wrist.

### 2.10.2 Joint Types

There are 4 types of joints, which may be used as standalone elements or form a serial

chain. The 4 types of joints a chain is revolute (R), prismatic (P), universal (U), and

spherical (S) joints. These 4 joints are schematically shown in Fig Combinations of

joint are used to create mechanisms.

8

### 2.10.3 Mechanism Type

A mechanism may be a serial, parallel, or hybrid depending on the relationship of its

linkage(s). A serial mechanism is a sequential connection of joints and links. For example,

a 2R mechanism (also known as an RR mechanism) is a 2DOF system composed of two

revolute joints located sequentially after one another. A parallel mechanism consists of 2

or more serial chains which span from a common base to a common distal platform, which

in this case is generally the TD. A hybrid mechanism, finally, is a combination of serial and

parallel mechanisms. This could be, for example, a parallel mechanism in series with a

serial mechanism, so that the base of one mechanism may not be fixed in space or the distal

part of one mechanism may not terminate in the end effector. An example of a hybrid

mechanisms occurs in the PKM Tricept T805 industrial robot, where a 3DOF parallel

mechanism terminates in a 3DOF serial wrist.

Possible combinations for actuation of wrist are listed below-

### 1. SINGLE-DOF WRISTS

A. Serial 1-DOF
1) Passive Serial 1-DOF:

2) Body-Powered Serial 1-DOF
3) Active Serial 1-DOF:
B. Parallel 1-DOF

### 2. 2-DOF WRISTS

Unlike single-DOF wrists, 2-DOF devices not only include prosthetic wrists,

(including those proposed in academic environments), but wrists used in robotic

applications, such as solar panel and camera orientation, as well.

A. Serial 2-DOF

There are only two combinations of serial wrist mechanisms resulting in 2-DOF

rotational motion, namely, revolute-revolute (RR) chains or universal (U) joints.

Both are employed regularly to achieve 2-DOF rotational motion.

1) Passive Serial 2-DOF
2) Body-Powered Serial 2-DOF
3) Active Serial 2-DOF
B. Parallel 2-DOF
1) Active Parallel 2-DOF

C. Hybrid 2-DOF

By the definition of hybrid mechanisms, hybrid 2-DOF wrists consist solely of a

single DOF rotator in series with a 1-DOF parallel mechanism. Only active hybrid

mechanisms were found, thus passive and body-powered sections shall be omitted.

1) Active Hybrid 2-DOF:

### 3. 3-DOF WRISTS

Wrist designs capable of 3-DOF rotational motion can arbitrarily orient their end-effectors (up

to a workspace limit). While the human wrist is naturally capable of 3-DOF motion, some of

the subsequently described wrists outperform the human wrist in some aspects, such as range

of motion or torque output, but generally not size or compactness.

A. Serial 3-DOF Serial
1) Passive Serial 3-DOF:
2) Active Serial 3-DOF:

B. Parallel 3-DOF

Parallel 3-DOF motions are capable of exhibiting fully spherical motion, though some

mechanisms are cable of coupled translation with 3-DOF rotation. Moreover, these

mechanisms are all active devices, so passive and body-powered subsections shall be

omitted.

1) Active Parallel 3-DOF:
2) Hybrid 3-DOF

### 2.10.4 Common issues with Wrist

Prostheses Major issues that limit the application of wrist prostheses are the additional weight

and limb length resulting from the integration of a wrist unit into an existing socket (worn over

the residual limb) and terminal device arrangement. Although additional weight of a prosthetic

can lead to fatigue and discomfort, excessive length can create a discrepancy between limbs

that impacts co-ordination and aesthetics. Upper limb prosthetics are already subject to

abandonment due to these reasons, even without the inclusion of a wrist. Though forearm

socket length may be reduced to accommodate the additional length of a wrist, this is only

applicable to amputees with relatively short residual limbs (proximal amputation). It is essential

to make the distinction between a wrist disarticulation amputee vs. a transracial (forearm) and

other type of upper limb amputee when preparing a prosthesis. In the former case, a long

residual limb prevents the prosthesis from occupying any forearm volume, whereas in the latter

cases, a portion of the forearm socket is available to house components of the prosthesis (such

as the battery in myoelectric devices).

### 2.11 DEVELOPMENT BOARDS

Development board is basically a printed circuit board with circuitry and hardware on-board to

facilitate experimentation with certain microcontrollers. These boards can save you from a lot

of repetitive tasks.

1. Arduino Development Board: ...
2. Raspberry Pi Development Board: ...
3. The BeagleBone Black Development Board: ...
4. The Intel Galileo Development Board: ...
5. The pcDuino Development Board:
6. The Uruk Development Board: ...
7. The Goldilocks Development Board: ...
8. The ExtraCore Development Board:
9. DIY Printed Circuit (PCB) Boards:

Arduino Development Board:

Arduino is the popular open-source electronics prototyping stage focused around simple to-

utilize equipment and software. It's proposed for specialists, designers, and anybody intrigued

by making intelligent articles or situations and is intended to be as adaptable as would be

prudent to fit your venture's necessities. The Arduino Development Board is a good example

of top development boards for DIY projects. Arduino is a company that deals with open source

computer hard ware and software. The company designs and does manufacturing of kits

creating digital devices and many interactive objects which have the capability of sensing and

making good control of the whole physical world. Since it is an example of a microcontroller,

it works swiftly and steadily. It is manufactured primarily by Smart Projects in Italy and many

other countries and vendors.

ARDUINO MEGA 2560 REV3

The MEGA 2560 is designed for more complex projects. With 54 digital I/O pins, 16

analogue inputs and a larger space for your sketch it is the recommended board for

3D printers and robotics projects. This gives your projects plenty of room and

opportunities.

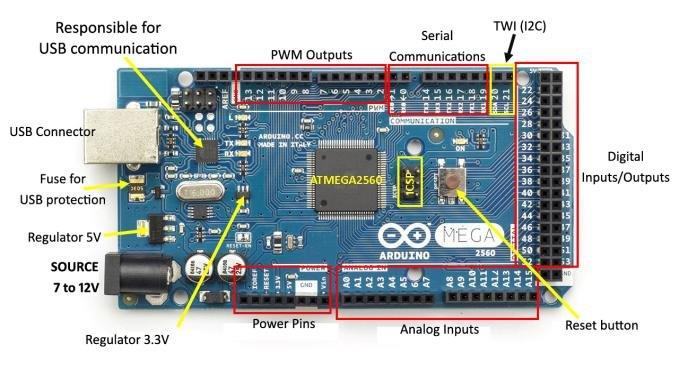
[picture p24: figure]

Fig 8. Controlling of servo actuation

H-Bridge

An “H-Bridge” is simply an arrangement of switching the polarity of the voltage applied to a

DC motor, thus controlling its direction of rotation. To visualize how this all works I’ll use

some switches, although in real life an H-Bridge is usually built using transistors. Using

transistors also allows you to control the motor speed with PWM, as described above.

In the first diagram we can see four switches which are all in the open or “off” position. In the

center of the circuit is a DC motor. If you look at the circuit as it is drawn here you can distinctly

see a letter “H”, with the motor attached in the center or “bridge” section – thus the term “H-

Bridge”.

If we close (i.e. turn on) two of the switches you can see how the voltage is applied to the

motor, causing it to turn clockwise.

Now we’ll open those switches and close the other two. As you can see this causes the polarity

of the voltage applied to the motor to be reversed, resulting in our motor spinning

counterclockwise.

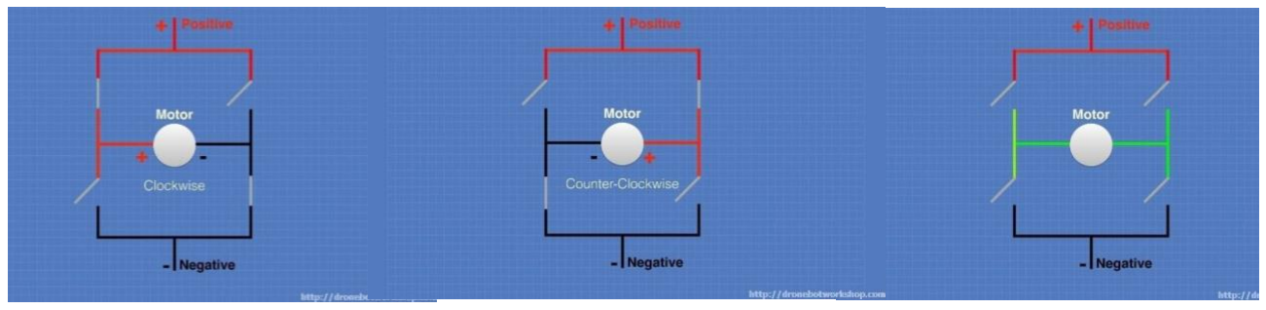
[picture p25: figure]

This is pretty simple but effective. In fact if all you need to do is design a circuit to drive the

motor

FIG 9 – H BRIDGE

full-speed in either direction you could actually build this as shown here, using a 4PDT (4 Pole

Double-Throw) center-off switch. But of course, we want to control the motor using an

Arduino, so an electronic circuit where the switches are replaced by transistors is what we need.

1) L298N Module Pinouts

You’ll find a few different styles of L298N boards but they all operate in the same fashion. The

board contains an L298N mounted on a heatsink, a 5 volt voltage regulator to “optionally)

provide power for logic circuits, supporting diodes and capacitors and connectors as follows:

- Logic inputs for each H-Bridge circuit
- Power supply inputs for the motor power supply
- An optional 5 Volt power input for the logic circuits.

- Outputs for each DC motor

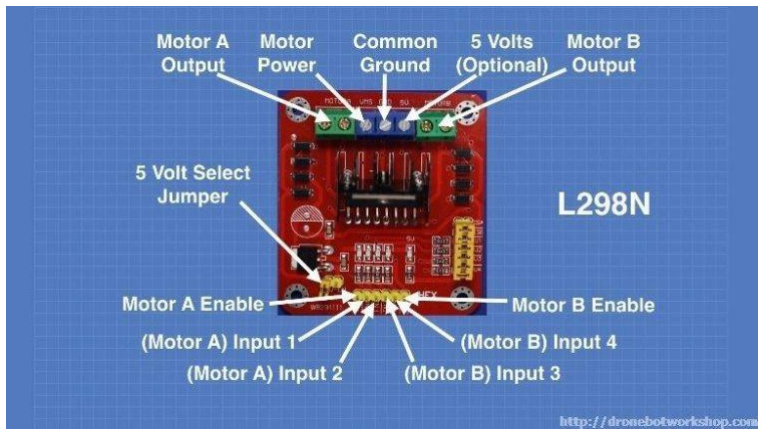
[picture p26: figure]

FIG 10 - L298N Module Pinouts

You’ll notice that the board also has a number of jumpers. Most of the time you will leave them

in place, with the exception of one. They are as follows:

- CSA – This is the “current sensing” function for Motor A. If the jumper is in this function is

ignored. Most of the time you’ll leave this jumper in place.

- CSB – The “current sensing” function for Motor B. Again, you’ll usually just leave this in

place to disable this function.

- U1 – Input 1 pull-up resistor. You will usually leave this in place, which enables a 10k pull-up

resistor for the input.

- U2 – Input 2 pull-up resistor.
- U3 – Input 3 pull-up resistor.
- U4 – Input 4 pull-up resistor.
- 5v-EN – This is the only jumper that you need to really pay attention to. When this jumper is

in place it enables the boards internal 78M05 5 Volt regulator, supplying logic power from the

motor power supply. When this jumper is enabled you will NOT supply 5 volts to the 5 Volt

input terminal. When the jumper is removed you will need to supply 5 Volts to the 5 Volt input

terminal.

If you do use the internal voltage regulator you’ll have to supply the motor power supply with

at least 7.5 volts.

Speaking of the motor power supply it needs to be a bit higher voltage than the actual motor

requirements. This is due to the internal voltage drop in the transistors that form the H-Bridge

circuit. The combined voltage drop is 1.4 volts, so if you are using 6 Volt motors you’ll need to give the board 7.4 volts, if you have 12 volt motors then your motor supply voltage will need

to be 13.4 volts.

The board has four input terminals plus two enable terminals. You will use these terminals to

control both direction and speed or each motor. They are as follows:

- IN1 – Input 1 for Motor A
- IN2 – Input 2 for Motor A
- IN3 – Input 3 for Motor B
- IN4 – Input 4 for Motor B
- EN1 – Enable line for Motor A
- EN2 – Enable Line for Motor B

In order to simplify things a bit I’ll just discuss the inputs and enable for Motor A, Motor B

functions identically.

The two Input lines control the direction that the motor rotates. I will call one direction

“forward” and the other one “reverse”, if it makes more sense to you just substitute “clockwise”

and “counterclockwise”.

You control motor direction by applying either a Logic 1 (5 Volts) or Logic 0 (Ground) to the

inputs. This chart illustrates how this is done.

INPUT 1 | INPUT 2 | DIRECTION
Ground (0) | Ground (0) | Motor Off
5 Volts (1) | Ground (0) | Forward
Ground (0) | 5 Volts (1) | Reverse
5 Volts (1) | 5 Volts (1) | Not Used

As you can see only two combinations are actually used to control the direction of the motors

rotation.

The Enable line can be used to turn the motor on, to turn it off and to control its speed. When

the Enable line is at 5 Volts (1) the motor will be on. Grounding the Enable line (0) will turn

the motor off.

To control the speed of the motor you apply a Pulse Width Modulation (PWM) signal to the

Enable line. The shorter the pulse width, the slower the motor will spin.

1) MD10C
- Introduction:

Enhanced 10Amp DC Motor Driver (MD10C) is (http://cytron.com.my/p-md10c) an enhanced version of the MD10B which is

designed to drive high current brushed DC motor up to 13A continuously (for Rev2.0). It offers

several enhancements over the MD10B such as support for both locked anti-phase and sign-

magnitude PWM signal as well as using full solid state components which result in faster

response time and eliminate the wear and tear of the mechanical relay.

Arduino main boards such as Arduino Uno (http://cytron.com.my/p-arduino-uno) are quite popular these days due to its easy-to-use

programming environment. Therefore, by interfacing Arduino main board with MD10C, we

gain easier control of DC motors. In addition, further adding an Arduino LCD Keypad

Shield can help us to control the DC motor that connected to MD10C with the 6 momentary

push buttons (built-in push buttons on LCD keypad shield including 1 Reset button) and also

display some useful message or information.

- How does MD10C work?

One of the features of MD10C is it supports both sign-magnitude and locked anti-phase PWM

signal, means you can control motor in 2 different ways!

- | Sign-magnitude | mode

You require 2 separate signals to control the motor, one is for direction (counterclockwise or

clockwise) and another is for the speed. To control motor direction, DIR pin is connected to

HIGH or LOW for different direction, whereas PWM pin is fed with PWM signal to control

| the motor speed.
- Locked anti-phase mode

In this mode, only 1 signal is required to control both speed and direction of motor. PWM pin

of MD10C is always connected to HIGH (5V), while DIR pin is fed with d to PWM signal.

The direction of motor depends on whether the duty cycle of PWM signal is less than or more

than 50%. The motor will run in one direction if the duty cycle is less than 50% and another

direction if more than 50%. The motor stops if duty cycle is 50% (approximately). The speed depends on the percentage of duty cycle.

Sign-magnitude VS Locked anti-phase

Main advantage of using locked anti-phase mode compare to sign-magnitude mode in motor

controlling is it reduces number of I/O pins used since it uses only 1 signal for controlling both

the speed and direction of motor. However, if locked anti-phase is used, in the beginning motor

will run at maximum speed (as you can see in the video) when there is no PWM signal. Users

will have to provide PWM signal at 50% duty cycle to DIR pin or set PWM pin (MD10C) to

LOW state in the beginning. In terms of programming, the algorithm will be more complex

because in locked anti-phase mode, motor speed changes with increment or decrement of PWM

value depends on the direction which the motor is at. Motor becomes slower with increment of

duty cycle if duty cycle of PWM signal


FIG 11 – CYTRON MD10C

is less than 50% or otherwise if duty cycle is more than 50%.

2) Md10a
- Introduction

MDD10A stands for Motor Driver Dual Channel 10(Amps). This DRIVER is the dual

channel version of MD10C which is designed to drive 2 brushed DC motors at high

current s up to 10A each, continuously. Just like MD10C, MDD10A also supports locked-

antiphase and sign-magnitude PWM control. It uses all solid-state components resulting

in faster response times and eliminates the wear and tear of mechanical relays.


FIG 12 - MD10A

BIONIC ARM DATA ACQUISITION AND CLASSIFICATION

Many different approaches are presently used to control the Bionic Arm. Some of the

widely used approaches are-

1. EEG signal analysis approach. 2. EMG signal analysis approach.

Electroencephalography (EEG) is an electrophysiological monitoring method to record

electrical activity of the brain. EEG measures voltage fluctuations resulting from ionic

current within the neurons of the brain[3]In EEG signal approach, the brainwaves are

sensed from different regions of brain. The Signal frequency range is around 1 to 500 Hz

and amplitude is around 50 micro volts[4]. These signals are weak in amplitude and have

a lot of noise. Plus, it is hard to distinguish between the signal for left and right hand

movements. In EMG signal approach, the brainwaves are sensed near the arm. This signal

is produced due to the neural and muscular activity. So the signal is comparatively strong

and easy to extract. Since the signal is sensed near the arm there is no problem of right and

left hand movement differentiation. In addition to that, processing EEG is complex and

consumes more power.

The EMG signal is a biomedical signal that measures electrical currents generated in

muscles during its contraction representing neuromuscular activities[5]. The amplitude of

the signal is in the range of 0-10 mV[5]. Signal frequency range is above 12 Hz. It is

proposed to use EMG signal approach since is easy to implement and gives better signal quality. With good analysis tools and algorithms, the EMG signals can be mapped with the

control signals for the servo motors in Bionic Arm with a high degree of accuracy.

There are two ways to extract the EMG signal.

1) Intramuscular EMG (invasive electrode)
2) Surface EMG (non-invasive electrode)

Commercially many different Bionic Arm options are available with a varying degree of

freedom in the motions. It is intended to design a Bionic Arm that mirrors as many motions

of the actual human hand as possible. For this, study of various actuators and robotic

mechanisms will be undertaken to design the Bionic Arm.

Sensors

The requirements for a sensor to successfully acquire EMG signal are as follows

- It should contain a 10-500Hz Band Pass filter to remove the high frequency noise from

the signal.

- It should contain a 50 Hz Notch filter for noise reduction.
- The signal strength of EMG signals is very low. It is in the range of 0-10 mV. Thus, the

sensor should have an amplifier to amplify the signal strength.

- A high-resolution ADC is needed to convert the EMG signal from analog to digital

value.

Along with sensors, right electrodes also need to be chosen to obtain accurate readings. There

are various types of electrodes available. Since we are going for sEMG signal extraction, the

non-invasive electrodes will be used. The signal extracted with dry electrodes tends to be noisy

and weak in strength. Conductive gel electrodes provide better signal extraction as compared

to dry electrodes but they need to be replaced regularly since the conductive gel is not long

lasting.

# 3.BIONIC ARM DESIGN

## 3.1 Palm Design

### Introduction

The aim of the project is to build a high DoF Bionic Arm which will be light in weight. Achieving high dexterity is a herculean task, so a step by step approach was undertaken. For incorporating dexterity in artificial robotic hand, the fingers of the hand should have more than one DoF. So initially the work initiated with designing and implementation of 1 DoF finger. The design of Bionic Arm is divided into 3 phases, following is the detail description of the phases-

### 3.1.1 Design Phase 1

The design process of Bionic Arm initiated with single DoF finger actuated by string mechanism. The string was actuated by high torque servo motors. The string mechanism consisted of a nylon string which was passed through the finger in such a way that when the string is pulled by adequate force, the finger flexes. Thus, providing a flexion and extension motion of finger.


Single DoF finger actuated by servo motor.

NRS 995 servo motor used for experimenting

Specifications of servomotor -
- Dimension-40.7mm x 20.5mm x39.5mm
- Torque-15.5kg/cm at 4.8V, 17kg/cm at 6V
- Dual bearing with metal gear
- Motor weight-60gms
- Operating speed-0.15sec/60 degree
- Operating voltage-4.8V to 6V
- Temperature range-0-55C
- 0.6 ms for 0-degree Rotation
- 2.2 ms for 180-degree Rotation

After pulling the strings, actuation is observed at PIP, DIP and MCP joints. Though the actuation is not an independent one, the movement at DIP and PIP are passive DoF.

Advantages

- Simple Mechanism due to use of servo motor and strings,
- Servo motor is easy to control.
- The total weight of the hand can be close to 500 grams.
- Simple Kinematics of the finger.

Disadvantages
- The mechanism is mainly based on the quality of strings; highly tensile strings are required which can endure millions of cycles of pulling forces. So, a high tensile string is required. But as amputees heavily use the artificial hand, the servo string mechanism will fail in long terms as string will fail to provide that tensile strength due to wear and tear.
- As it is only 1 DoF per finger, it has less dexterity.
- String-servo motor mechanism can only give flexion and extension motion and lack of feedback in servo motors leads to inefficient actuation.
Thus, it was concluded that servo string mechanism cannot be used to design fingers with more than one active DoF.

## 3.1.2 Design Phase 2

After experimenting with servo string mechanism, design phase 2 was initiated. In phase 2 of design, after considering the advantages and disadvantages of previous mechanism it was decided to continue with the same finger model. This time rather than using a servo motor, Johnson DC motor was used.
The purpose of using a DC motor was to incorporate precise control over flexion and extension motion of the finger. Here for actuation of finger, rather than using single string, a twisted string was used. The DC motor was coupled to two strings and the rotatory motion of DC motor twisted the strings leading it to linear actuation which flexed the finger.
Specifications of Johnson DC Motor-
- Base Motor RPM-18000
- Operating Voltage-6-18 V
- Rated Voltage-12 V
- Rated Torque-7.5 kg-cm
- Stall Torque-30 kg-cm
- Gearbox Dimensions-25×37 (LxW) mm

Twisted String Actuation using DC motor


Finger mounted on holder, holding Johnson DC motor

Advantages
4 Johnson DC motor provided enough torque which was converted to force imparted on the tip of the finger.
5 Precise angular control of the finger.
6 Adequate grasping was achieved.

Disadvantages
7 Johnson DC motor provided enough torque but at the cost of its high weight due to heavy metal gears. 60 RPM motor weighted 164 grams. So, weight of single finger mechanism was about 180 grams. This will lead to overall weight of arm up to 1kg.
8 High weight was not acceptable as it is not suitable for amputee to use such a heavy artificial arm.
9 Arm has used Maxon motors with planetary gears. Maxon motor are costly and are not feasible for low cost Bionic Arm design.
10 Less dexterous.

Thus, this mechanism was not feasible solution for the problem statement.

## 3.1.3 Design Phase 3

Need for Design Phase 3
11 After experimenting on two mechanisms, a better mechanism for fingers was required which will provide more DoF and dexterity.
12 While maintaining the dexterity, goal of light weight prosthetic was also to be achieved. 13 Though DC motor and Servo motors are famously used for actuation in robotic arms and prosthetic arms, a different type of light weight and high force imparting actuator was needed to address the problem statement.
14 Thus, it paved the roads for the design phase 3.

Block Diagram of Proposed System

Working of the Bionic Arm- As finalization of incorporating of linear actuator in the Bionic Arm was done, detail working of Bionic Arm is as follows-

Working of PQ12 Linear Actuator Linear Actuator consist of following parts-

In linear actuator linear motion is obtained from conversion of rotational motion of DC motor. The DC motor is connected to set of gears which improves the torque, while the set of gears are also connected to lead screw. The lead screw moves in linear direction. So, as the motor rotates, lead screw moves in linear direction.

Mechanism Design and incorporation of Linear Actuators in the mechanism-

Linear Actuator works on the principle of slider crank mechanism. These slider crank mechanisms provide linear movement. This linear movement has to be converted into rotatory motion. So, to have angular motion at joints of finger, a revolute joint is introduced by a small link at the MCP and PIP joints of the finger. The finger mechanism was designed in 3DExpereince platform, which provided many tools like Part Design, Assembly Design, Mechanical System Design.

Thus, using 3DExperience entire Bionic Arm was designed


Linear actuator connected to a revolute joint link for actuation at MCP joint

Here to improve the DoF, PQ12 actuator is placed in proximal phalange of a finger to actuate PIP joint and another PQ12 actuator is placed in the palm to actuate MCP joint. Thus, each finger is actuated by two Linear actuators and each finger thus has two active DoFs.

The Figure 6-7describes the mechanism of MCP revolute joint. A small link was designed which converted linear actuation into rotatory actuation. The link was connected to the shaft of the linear actuator by a screw. When linear actuator extends up to 16 mm, the finger was rotated about that link for 90 degrees. Thus, there was rotation for 0-90 degrees at MCP joint, which also mimicked the human finger rotation at MCP joint.


Actuator in Proximal Phalange for actuation at PIP joint

The above Figure 6-8describes actuation at proximal joint. Here a separate DoF is introduced at PIP joint. An independent DoF at proximal joint helps for stable pinch and lateral grasp. This also improves the dexterity of the Bionic Arm. A linear actuator is placed in proximal phalange of the finger. The design was such that when the actuator extends, the upper part of the proximal joint was supposed to rotate for 90 degrees.

One more feature added to this joint was that it was connected to the DIP joint of the finger by a link. The famous four bar mechanism was implemented between PIP and DIP joint. The implementation of four bar mechanism lead to the relative movement of DIP joint with respect to PIP joint Due to this motion, an intuitive finger motion was implemented which had an anthropomorphic design.


Thumb assembly and actuation on servo motor

The thumb is an important part of human hand. Without thumb, it would be impossible to achieve any kind of grasp. So, the goal was to improve the dexterity of the thumb. In human hand thumb has 5 DoFs but implementing 5 DoFs in thumb was not an easy task. So only main and important DoF/movement of thumb had to be selected. After studying the role of thumb in object grasping ,3 DoFs were selected. Following were the 3 DoF selected-

-DoF) of thumb was implemented by mounting thumb on a servo motor which rotated from 0 to 90 degrees.

The actuation at this joint was important for pinch grasp

b phalange for actuation at MCP joint (1 DoF). The actuation at this joint was important for lateral grasp

Thus, 3 DoF for thumb was implemented.


Bionic Arm assembly (11 DoF.)

Total DoFs in the Bionic Arm-

- Each finger has two DoFs, so total DoF
important part of our hand and all the stable grasps are achieved due to thumb. A decision was taken to increase the DoF of thumb. So, thumb had 3 DoF.
- The thumb of Bionic Arm has actuation at IP joint and MP joint as well as flexion and extension movement of finger was implemented using servo motor fixed in palm.
- Thus, total DoFs in the Bionic Arm is 11.

### 3.2 Design of Wrist

Introduction
The human wrist contributes greatly to the mobility of the arm/hand system, empowering dexterity and manipulation capabilities. Wrists can improve manipulation capabilities, as they can orient the end-effector of a system without imparting significant translational motion.
The healthy human wrist serves as an effective baseline toward which prosthetic wrists are designed, and a point of reference for which any orientation device may be considered. It is capable of motion in 3-DOFs, namely pronation/supination, flexion/extension, and radial/ulnar deviation. Each DOF is a paired set of motions, referring to positive and negative motion within each DOF.

### 3.2.1 Mechanism selection

After studying different types of articulation methods, joint types of healthy human wrist and mechanism types, it was decided to design and manufacture the wrist having 3 Dof.
Universal joint-A universal joint is a positive, mechanical connection between rotating shafts, which are usually not parallel, but intersecting. They are used to transmit motion, power, or both.


FIG 13 – UNIVERSAL JOINT

The universal joint was appropriate for the purpose because of following reasons-

- Torque transmission efficiency is high.
- The joint permits angular displacements.
- Low side thrust on bearings.
- Large angular displacements are possible.
- High torsional stiffness.
- Simple design.

3.2.2 Design Stage 1.

- Slots for motor drivers

To make the connection of actuating wires and motor drivers easier and understandable

and also for providing correct position to motor driver boards so that no incorrect

positioning of boards will happen the slots are provided. This makes connection of wires

from outer side of the palm and hence in case of any damage, repairing becomes easier.

### 4 Palm cover

This is used to give better aesthetic appearance to the palm and also to give support to the palm during its rotation.

### 5 Link 1 and Link 2

Drawings below show the selected motor (MG 995) and links used to connect motor

and to give proposed wrist motion to the palm. The link 1 is used to give front-back

motion to the palm and link 2 is used to give side by side motion to the palm. A

casing is made to cover the motor to give it stiffness while mounting.


6 | Assembly of palm cover link 1 and link 2 CAD model below shows the assembly of palm, cover, links and the mounting plate.
| This assembly is used for giving 2 Dof to the palm.

### 7 Link 3


### 8 Wrist

### 9 Final assembly

Need for design stage 2 –

1. Previous design is aesthetically poor as it consists of many gaps between the links.
2. Some unnecessary links can be eliminated.
3. Some mechanism can be added at the bottom to reduce friction at bottom part.

## 3.3.3 Design Stage 2-

In design stage 2, the basic mechanism of wrist was kept same but some unnecessary links were removed and links were given round shape from inner side to give perfect hinge type motion. From new links it was easier to locate exact position of motors. Also, bearing is added at the lowest portion to reduce friction and support rolling action.

Following snapshots explains the design. Wrist was also designed using 3D-Experience software.

10 Back cover

11 | Link 1
12 | Link 2

13 Link 3

Circular slot is made on the top to accommodate bearing to support rotary motion.

Flanges provide mounting of arm and supports the arm.

14 Assembly of wrist


Assembly of arm


# 4.CALCULATIONS

### 4.1 Selection of motor

### 4.1.1 Selection Procedure

The data required for selection of motor is as followed-

- Dimensions and mass (or density) of load
- Dimensions and mass (or density) of each part
- Friction coefficient of the sliding surface of each moving part

The required specifications for the equipment are:

- Operating speed and operating time
- Positioning distance and positioning time
- Resolution
- Stopping accuracy
- Position holding
- Power supply and voltage
- Operating environment
- Specific features and requirements such as; Open-Loop, Closed-Loop, Programmable,

Feedback, IP rating, Agent approvals, etc.

4.1.2 Motor Sizing Calculations

There are three factors to calculate when sizing a motor; Moment of Inertia, Torque, and

Speed.

Moment of Inertia

Moment of inertia is the measure of an object's resistance to changes in its rotation rate.

When an object is just sitting without any motion, the moment of inertia is 0.

When you try to make it move that mean you want to change the speed of the object from 0

to any, there will be moment of inertia effect.

Moment of Inertia Calculation for a Rotating Object

### 4.1.3 Torque:

Torque is the tendency of a force to rotate an object about an axis. Torque is made up of two

components; a load (constant) component and an acceleration component.

The load torque component is usually due to friction and/or gravity and is always acting on

the motor. This component can usually be determined by calculation or by putting a torque

wrench on the system and reading the torque value. When it is not able to measure, then we

use some equations to calculate the approximate value.

The acceleration torque however, is only acting on the motor when it is accelerating or

decelerating. Once the motor is running at a constant speed, this component goes away.

Measuring the acceleration component is difficult not to mention dangerous. If you want the

load to be up to speed within 50 milliseconds, it’s likely that a torque wrench will fly off.

Therefore, we calculate the acceleration component. This component is a function of the

inertia of the system and the acceleration rate. So, once we determine these values, we can

figure out the acceleration torque.

### 4.1.4 Load Torque ( T )

Load torque is very simple.

As you see this equation torque is the product of the force and the distance between the force

and the center of rotation. For example, if you want to hold the force acting on the end of

pulley, T = F x r. So calculating load torque is determine the force in the system and the

logical distance between the motor shaft and the where the force is acting.

When the mechanics become complicated, we need to convert the F and r to fit the mechanics.

With each application, the drive system requirements greatly vary.

DC Servomotors

Advantages | Disadvantages
Smooth operation, low-velocity ripple | Brushes limit ability to continuously start and stop
High torque | Brushes require maintenance

### 4.1.5 Stall torque calculations

Stall torque is the torque produced by a mechanical device whose output rotational speed is

zero. It may also mean the torque load that causes the output rotational speed of a device to

become zero, i.e., to cause stalling. Electric motors, steam engines and hydrodynamic

transmissions are all capable of developing torque when stalled.

Stall torque = force * displacement

Observed data,

Total mass of the system (m) = 656 gm

Distance of centre of mass (r) = 7.376 cm

Now,

Stall torque = mg * r

= | 0.656* 9.81 * 0.07376 N. m
= | 0.4736 N. m
= 0.656 * 7.376 kg.cm | = 4.8386 kg.cm

Given,

Operating voltage = 5 v

Ѡ | = (60 degrees/0.2 sec) = 5.235 rad/sec,
torque | = 10 kg.cm

power rating (@ 4.8v) = torque * Ѡ

| = 0.10 * 9.81 *5.235 = 5.135 watts

4.2 BEARING SELECTION; arm.; specifications.; Mounting points for 3; Space for bearing

Because of the position of motor, the only constraint for selection of bearing was dimensions of the bearing. The bearing should be placed such that it is centrally aligned with the upper

For the current movement of arm, we selected Thrust ball bearing having following rd motor Centrally aligned motor shaft hole

4.2.1 Specifications of 51110 Thrust Ball Bearing 50x70x14mm –

SKF Single direction thrust ball bearings consist of a shaft washer, a housing washer and a ball and cage thrust assembly. The bearings are separable so that mounting is simple as the washers and the ball and cage assembly can be mounted separately. Single direction thrust ball bearings, as their name suggests, can accommodate axial loads in one direction and thus locate a shaft axially in one direction. They must not be subjected to any radial load.

# 5.MANUFACTURING PROCESS

# AND

# MATERIAL SELECTION

## 5.1 Manufacturing Process

### 5.1.1 Introduction:

It is wise to think about the best tools and processes to finish your design when you want to

develop a product prototype. The three primary ways to make prototypes are subtractive

manufacturing (CNC machine parts), injection molding (designed to pre-produce prototypes),

or additive manufacturing (3D printing).

3D printing, refers to the process of producing 3-dimensional solid objects from a computer

file. Printing happens in an additive process where a solid object is developed through the

successive layering of material. There are a wide range of materials to choose from including

plastic and metal. The procedure starts with the creation of a 3D digital file such as Computer

Aided Design. The 3D digital file is then sent to a 3D printer for printing using a simple print

command.

### 5.1.2 Benefits of using 3D Printing-

- Better Quality

3D printing allows the step-by-step assembly of the object, which guarantees enhanced designs

and eventually better-quality objects.

- Tangible Design and Product Testing

There’s no way seeing a product on the screen or virtually can compare to the actual feel of a

prototype. 3D printing offers that benefit. It is possible to experience the touch and feel of the

product prototype to physically test it and find flaws in the design. If a problem is found, you

can modify the CAD file and print out a new version by the next day.

- Cost-effectiveness
- Creative Designs and Customization Freedom

3D printing allows for endless personalization, which makes it much simpler to accommodate

personal touches

- Unlimited Shapes and Geometry

Old methods of manufacturing rely on moulds and cutting technologies to generate the desired

shapes. Designing geometrically complex shapes can be hard and expensive with this technology. 3D printing takes on this challenge with ease and there’s not much the technology

can’t do with the proper support material.

- Less Waste Production

3D printing only uses material that is needed to create a prototype part – no more, no less. As

a result, additive manufacturing creates very little waste, and saves a company a lot of money.

- Risk Reduction

3D printing technology enables product designers to verify product prototypes before starting

out on substantial manufacturing investments that can sometimes be disastrous.

In addition to above all advantages, we were Provided by a 3D printer in our college by

Dassault systems. So, using 3D printer was more preferable. Products are built quickly and

cheaply with the 3D printing technology.

Because of all above reasons we used 3D printing technology for manufacturing prototype of

bionic arm.

## 5.2 Material Selection –

After selecting manufacturing process, it is crucial to select right material for the purpose.

There are various materials such as ABS, PLA, HIPS, PETG, PVA, Polycarbonate etc.

available in the market.

The main selection criteria was machine available with us in the college which is FDM (Fused

deposition modelling) machine. PLA and ABS are the 2 most common FDM desktop printing

materials. Both are thermoplastics, meaning they enter a soft and mouldable state when

heated and then return to a solid when cooled. Via the FDM process, both are melted and

then extruded through a nozzle to build up the layers that create a final part.

### 5.2.1 Comparison between ABS and PLA

Properties | ABS | PLA
Tensile Strength | 27 MPa | 37 MPa
Elongation | 3.5 - 50% | 6%
Flexural Modulus | 2.1 - 7.6 GPa | 4 GPa
Density | 1.0 - 1.4 g/cm³ | 1.3 g/cm³
Glass Transition Temperature | 105 ℃ | 60 ℃
- Part accuracy

ABS and PLA can be used to create dimensionally accurate parts, printing details down to 0.8

mm and minimum features down to 1.2 mm. Due to its lower printing temperature, PLA, when

properly cooled, is less likely to warp (making it easier to print with) and can print sharper

corners and features compared to ABS.

- Strength

With similar tensile strengths, ABS and PLA are both adequate for many prototyping

applications. 3D printed ABS can be employed for end use applications whereas PLA remains

popular for rapid prototyping when form is more critical than function.

- Surface finish and post processing

ABS typically print in a matte finish while PLA is semi-transparent, often resulting in a glossier

finish. PLA is ideal for 3D prints where aesthetics are important. Due to its lower printing

temperature is easier to print with and therefore better suited for parts with fine details,

In additional, PLA is Strong material, has Low cost and is easy for post-production PLA was

selected as a working material

PLA (Polylactic Acid) is a biodegradable (under the correct conditions) thermoplastic derived

from renewable resources such as corn starch or sugarcane. It is one of the most popular

bioplastics, used for many applications ranging from plastic cups to medical implants.

# 6.ACTUATION OF WRIST

### 6.1 Why Arduino?

Thanks to its simple and accessible user experience, Arduino has been used in thousands of

different projects and applications. The Arduino software is easy-to-use for beginners, yet

flexible enough for advanced users. It runs on Mac, Windows, and Linux. Teachers and

students use it to build low cost scientific instruments, to prove chemistry and physics

principles, or to get started with programming and robotics. Designers and architects build

interactive prototypes, musicians and artists use it for installations and to experiment with new

musical instruments. Makers, of course, use it to build many of the projects exhibited at the

Maker Faire, for example. Arduino is a key tool to learn new things. Anyone - children,

hobbyists, artists, programmers - can start tinkering just following the step by step instructions

of a kit, or sharing ideas online with other members of the Arduino community.

There are many other microcontrollers and microcontroller platforms available for physical

computing. Parallax Basic Stamp, Netmedia's BX-24, Phidgets, MIT's Handyboard, and many

others offer similar functionality. All of these tools take the messy details of microcontroller

programming and wrap it up in an easy-to-use package. Arduino also simplifies the process of

working with microcontrollers, but it offers some advantage for teachers, students, and

interested amateurs over other systems:

- Inexpensive - Arduino boards are relatively inexpensive compared to other microcontroller

platforms. The least expensive version of the Arduino module can be assembled by hand, and

even the pre-assembled Arduino modules cost less than $50

- Cross-platform - The Arduino Software (IDE) runs on Windows, Macintosh OSX, and Linux

operating systems. Most microcontroller systems are limited to Windows.

- Simple, clear programming environment - The Arduino Software (IDE) is easy-to-use for

beginners, yet flexible enough for advanced users to take advantage of as well. For teachers,

it's conveniently based on the Processing programming environment, so students learning to

program in that environment will be familiar with how the Arduino IDE works.

- Open source and extensible software - The Arduino software is published as open source

tools, available for extension by experienced programmers. The language can be expanded

through C++ libraries, and people wanting to understand the technical details can make the

leap from Arduino to the AVR C programming language on which it's based. Similarly, you

can add AVR-C code directly into your Arduino programs if you want to.

- Open source and extensible hardware - The plans of the Arduino boards are published under

a Creative Commons license, so experienced circuit designers can make their own version of

the module, extending it and improving it. Even relatively inexperienced users can build

the breadboard version of the module in order to understand how it works and save money.

### 6.1.1 Why Arduino MEGA 2560 ?

The MEGA 2560 is designed for more complex projects. With 54 digital I/O pins, 16

analog inputs and a larger space for your sketch it is the recommended board for 3D

printers and robotics projects. This gives your projects plenty of room and

opportunities.

The Arduino Mega 2560 is a microcontroller board based on the ATmega2560. It

has 54 digital input/output pins (of which 15 can be used as PWM outputs), 16 analog

inputs, 4 UARTs (hardware serial ports), a 16 MHz crystal oscillator, a USB

connection, a power jack, an ICSP header, and a reset button. It contains everything

needed to support the microcontroller; simply connect it to a computer with a USB

cable or power it with a AC-to-DC adapter or battery to get started. The Mega 2560

board is compatible with most shields designed for the Uno and the former boards

Duemilanove or Diecimila.

### 6.1.2 Pulse Width Modulation (PWM)

A far better method of controlling DC motors is to use pulse width modulation or PWM. If

you’ve read up on controlling LED’s with your microcontroller you probably have already run

into PWM as it’s also a good method of controlling the brightness of an LED.

With PWM the motor is sent a series of pulses. Each pulse is of the full voltage that the motor

can handle so a 6-volt motor will be sent 6-volt pulses while a 12-volt motor will be sent 12-

volt pulses. The width of the pulses are varied to control the motor speed, pulses with a narrow

width will cause the motor to spin quite slowly. Increasing the pulse width will increase the

speed of the motor, as illustrated below.

In order to stop the motor completely you just stop pulsing it, essentially sending it zero volts.

To run it at full speed you send it the full voltage, again without pulsing it. You can build a

simple PWM generator using a 555 timer and discrete components but it’s a lot easier to use

an Arduino. The Arduino has a function called “analogWrite” which is used to drive any of its

PWM-capable outputs (the Arduino Uno has 6 digital outputs that are also capable of PWM).

### 6.2 Miniature Linear Motion actuation

PQ12 Actuonix Motion Devices unique line of Miniature Linear Actuators enables a new

generation of motion-enabled product designs, with capabilities that have never before been

combined in a device of this size. These tiny linear actuators are a superior alternative to

designing your own push/pull mechanisms. Their low cost and easy availability make them

attractive to hobbyists and OEM designers alike. The PQ12 actuators are complete, self-

contained linear motion devices with position feedback for sophisticated position control

capabilities, or end of stroke limit switches for simple two position automation.

PQ12 Controller Options

Option P – Potentiometer Position Feedback WIRING: (see next page for pin numbering)

1 – Feedback Potentiometer negative reference rail

2 – Actuator Motor Power

3 – Actuator Motor Power

4 – Feedback Potentiometer positive reference rail

5 – Feedback Potentiometer wiper

The –P actuators have no built-in controller, but do provide analogue position feedback. While

voltage is applied to the motor power pins (2 & 3) the actuator extends. Reverse the polarity

and the actuator retracts. Position of the actuator stroke can be monitored using the internal

linear potentiometer. Provide any stable low and high reference voltage on pins 1 & 4, then

read the position signal on pin 5. The voltage on pin 5 will vary linearly between the two

reference voltages in proportion to the position of the actuator stroke. Connect to a LAC board

for easy interface with any of the following control signals: Analog 0-5V or 4- 20mA, or Digital

0-5V PWM, 1-2ms Standard RC, or USB.

Option R – RC Linear Servo WIRING:

1 - RC input signal (RC-servo compatible)

2 - Power (+6 VDC)

3 - Ground

The –R actuators or ‘linear servos’ are a direct replacement for regular radio-controlled hobby

servos. The desired actuator position is input to the actuator on lead 1 as a positive 5 Volt pulse

width signal. A 2.0 MS pulse commands the controller to fully retract the actuator, and a 1.0

ms pulse signals it to fully extend. If the motion of the actuator, or of other servos in your

system, seems erratic, place a 1–4Ω resistor in series with the actuator’s red V+ lead wire. The

PQ12–R Linear Servos are designed to work with typical RC receivers and battery packs.

Consequently, they also are compatible with Arduino control boards, VEX Microcontrollers

and many other similar boards designed for robotics.

Actuator dimensioning and wiring diagram

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

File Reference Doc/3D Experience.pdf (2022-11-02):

## 3D Experience

### What is 3D Experience –

The 3DEXPERIENCE platform is Cloud based BUSINESS EXPERIENCE platform. It provides software solutions for every organization in your company - from marketing to sales to engineering – that help you, in your value creation process, to create differentiating consumer experiences.

3DEXPERIENCE® is the next step after Product Lifecycle Management (PLM).


Let us look at the four quadrants, starting at the top and work around the quadrant in a clockwise direction:

1. Collaboration apps include functionality that foster informal collaboration across extended teams (SWYM) and structured collaboration such as formal change management (ENOVIA)
2. Information intelligence apps are designed to handle Big Data and drawing from multiple sources, present the user with concise summaries of the information they need (NETVIBES)
3. Simulation apps are aimed at virtual digital validation and testing of designs. Traditionally this is known as CAE or FEA (SIMULIA). It can also be extended to virtual simulation of factories or retail store layouts.
4. 3D Modelling apps are perhaps what Dassault Systems is best known for and include CATIA and Solidworks.

Install the 3DEXPERIENCE Launcher


A pop-up window to download 3DEXPERIENCE Launcher installer will appear after clicking your rich app from the IFWE Compass if the 3DEXPERIENCE Launcher (if not already installed on your computer).


At the end of the installation the service will start and an icon will appear in the system tray.

Refresh your browser page before starting the Native Apps Installation process (press F5 on your
keyboard).


After download, run the
3DEXPERIENCE Launcher msi
installer.

Installing the Apps

When your 3DExperience account is generated you will receive an email From Dassault Systèmes: 3dexperience@3ds.com. This email contains the link for registering and activating your account. Check your junk mail folder. Internet Explorer seems to provide the most consistent experience with the Dassault Systèmes website. The only operating system supported is Windows.
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

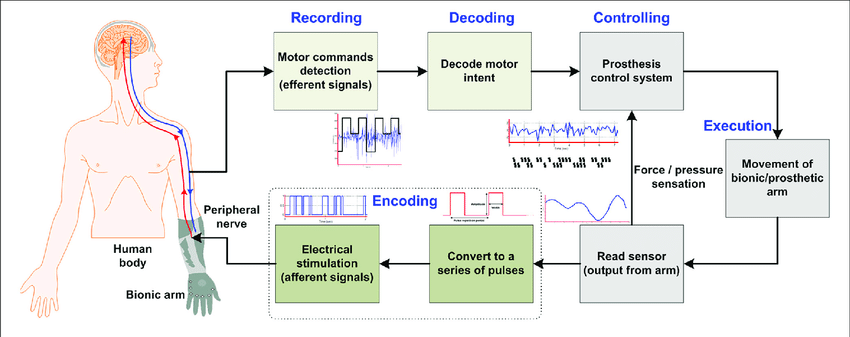
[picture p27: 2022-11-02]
study_doc/Concept-of-bi-directional-control-for-bionic-arm-systems.png

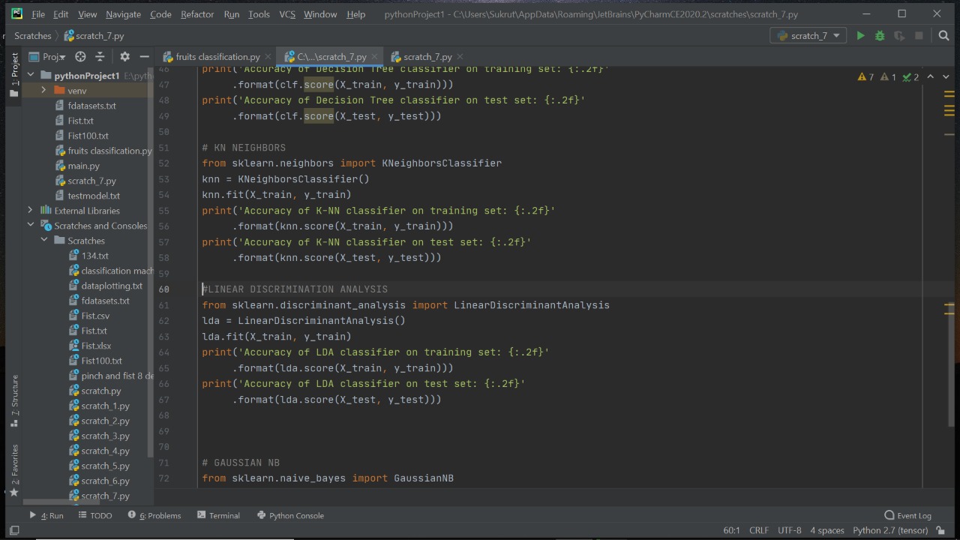
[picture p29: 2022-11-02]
snaps/WhatsApp Image 2020-12-13 at 8.25.53 PM.jpeg

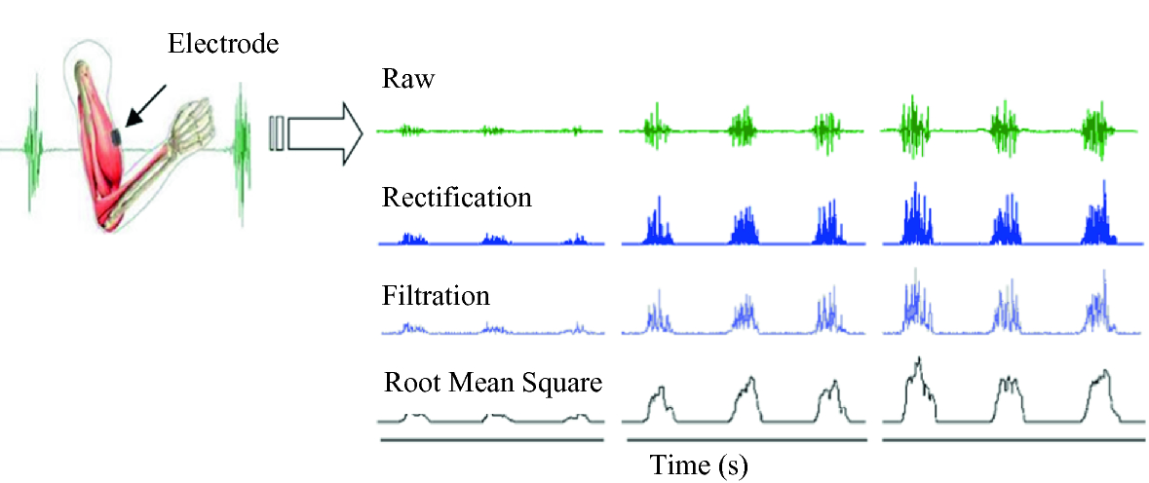
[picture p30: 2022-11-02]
study_doc/479535_1_En_20_Fig3_HTML.png

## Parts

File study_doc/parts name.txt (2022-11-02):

20-9-19
initial wrist mechanism
pp1
pp2
pp3
pp4
pp5
pp_main

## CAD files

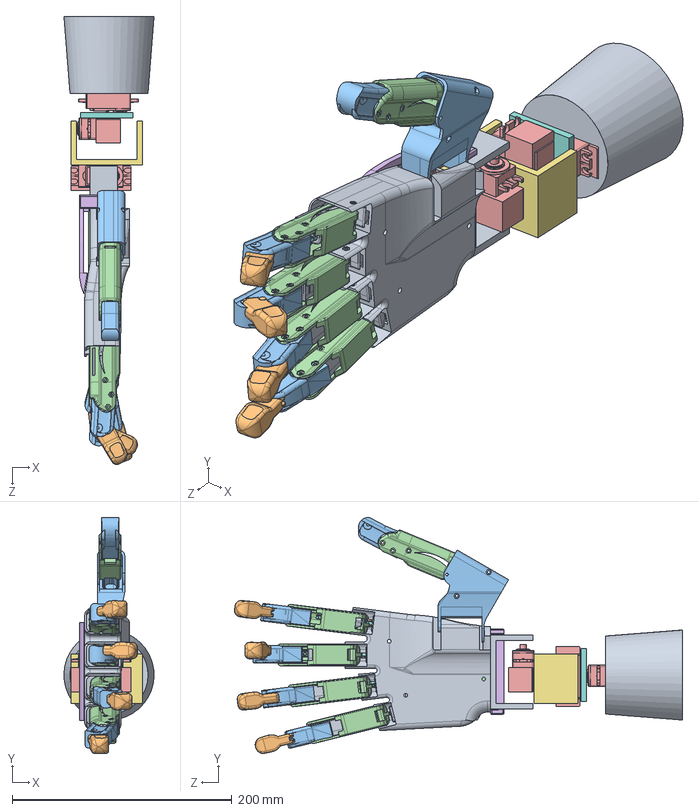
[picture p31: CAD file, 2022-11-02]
PARTS_SOLIDWORKS/bIONIC ARM.SLDASM
82.0 x 214.6 x 407.3 mm
DISTAL x 4
MIDDLE x 5
PROXIMAL x 5
ACT_1
ACT2
ACT3
ACT_STROKE x 8
ACTUATOR_BODY x 8
LINK1
THUMB_BASE
TRIAL
MG995 x 3
TRIAL 3
square plate
coveringgggg

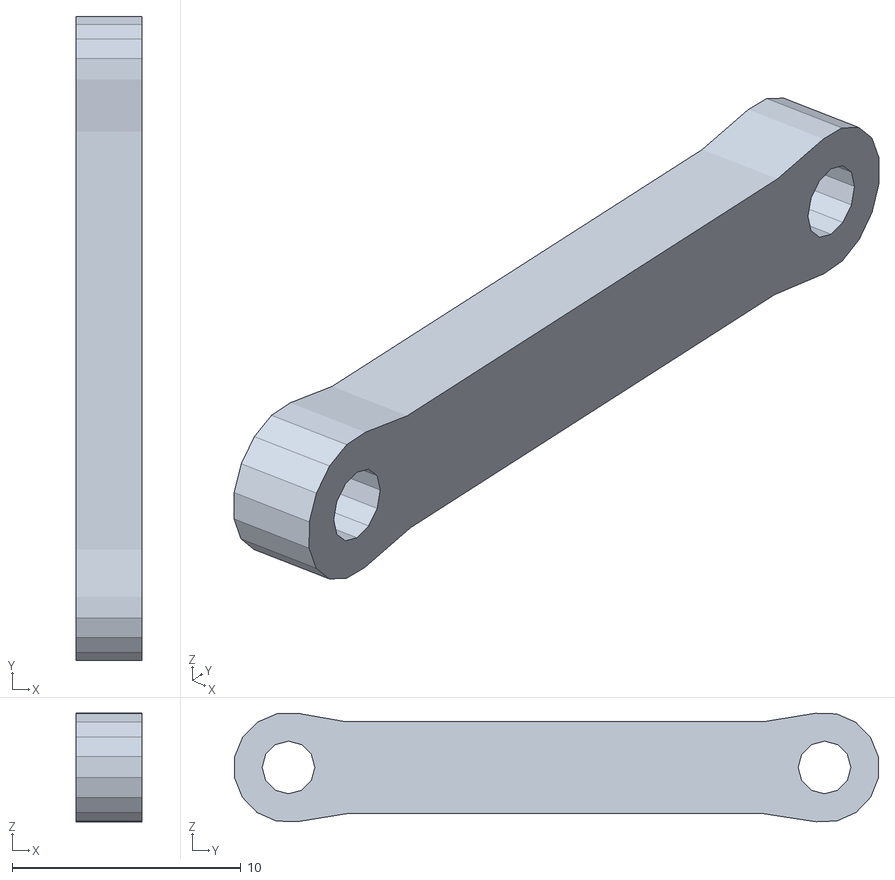
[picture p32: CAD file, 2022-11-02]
PARTS_SOLIDWORKS/finger assembly/four_bar_BA A.1.stl
2.90 x 28.1 x 4.74

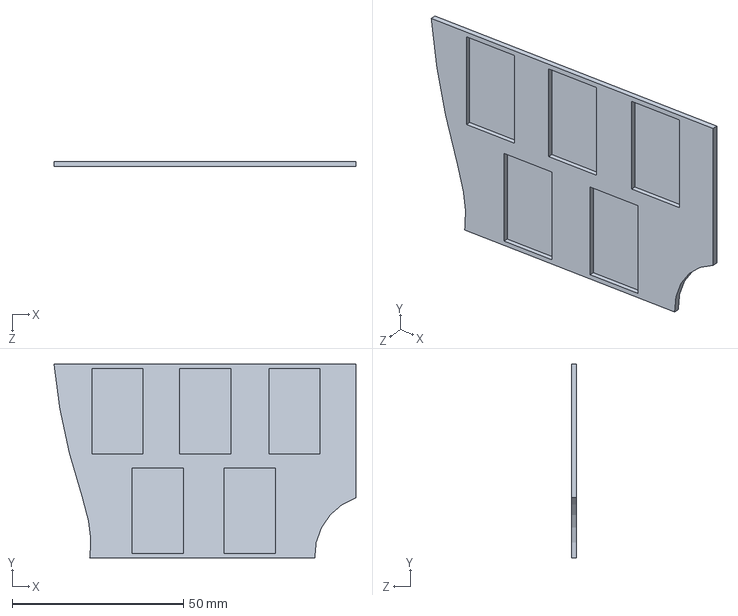
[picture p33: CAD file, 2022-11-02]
PARTS_SOLIDWORKS/TRIAL.SLDPRT
88.2 x 56.5 x 1.50 mm

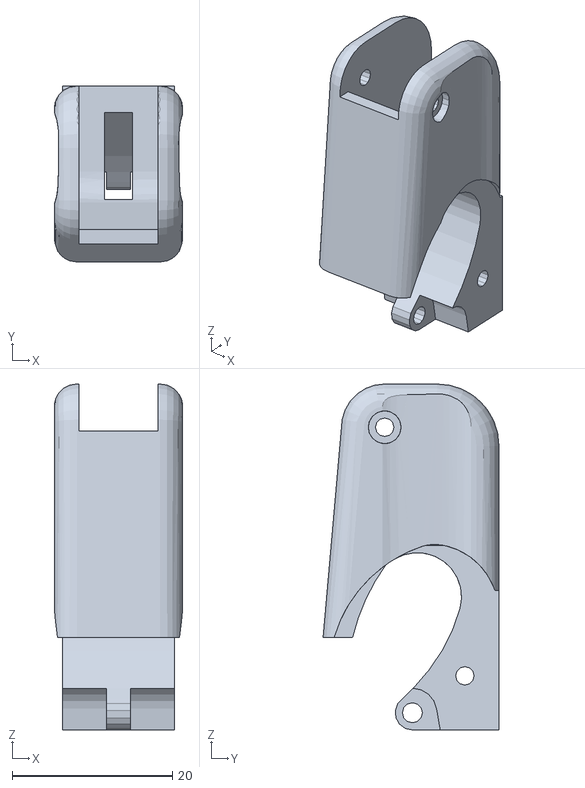
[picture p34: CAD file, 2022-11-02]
PARTS_SOLIDWORKS/finger assembly/middle_BA A.1.stl
16.0 x 21.9 x 43.1

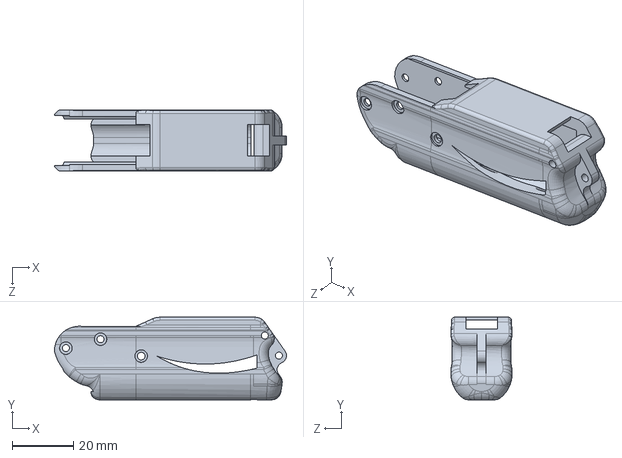
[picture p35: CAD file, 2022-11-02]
PARTS_SOLIDWORKS/PROXIMAL.SLDPRT
75.8 x 27.0 x 20.0 mm

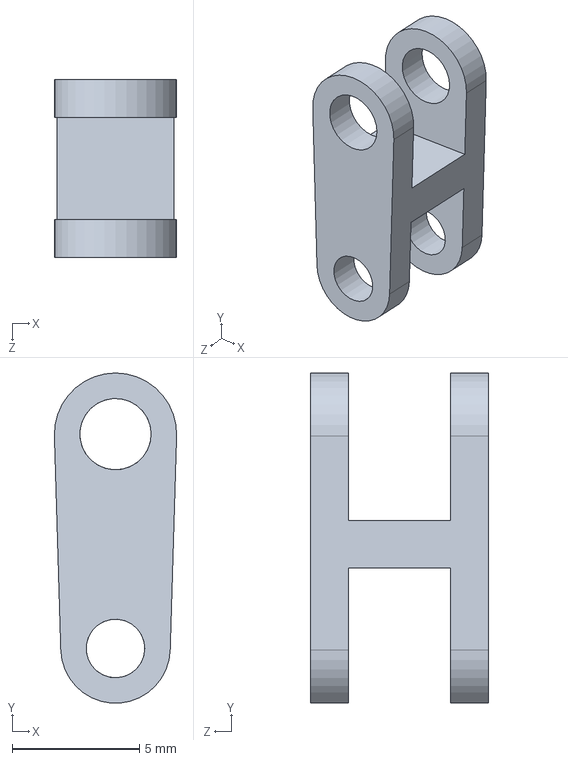
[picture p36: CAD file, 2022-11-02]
PARTS_SOLIDWORKS/LINK1.SLDPRT
4.80 x 13.0 x 7.00 mm

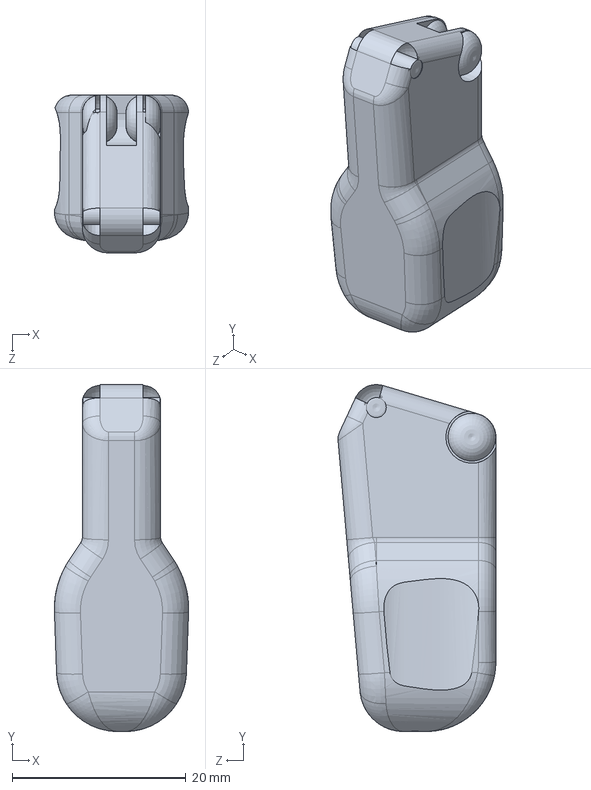
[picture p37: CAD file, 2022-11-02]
PARTS_SOLIDWORKS/DISTAL.SLDPRT
15.4 x 39.9 x 18.2 mm

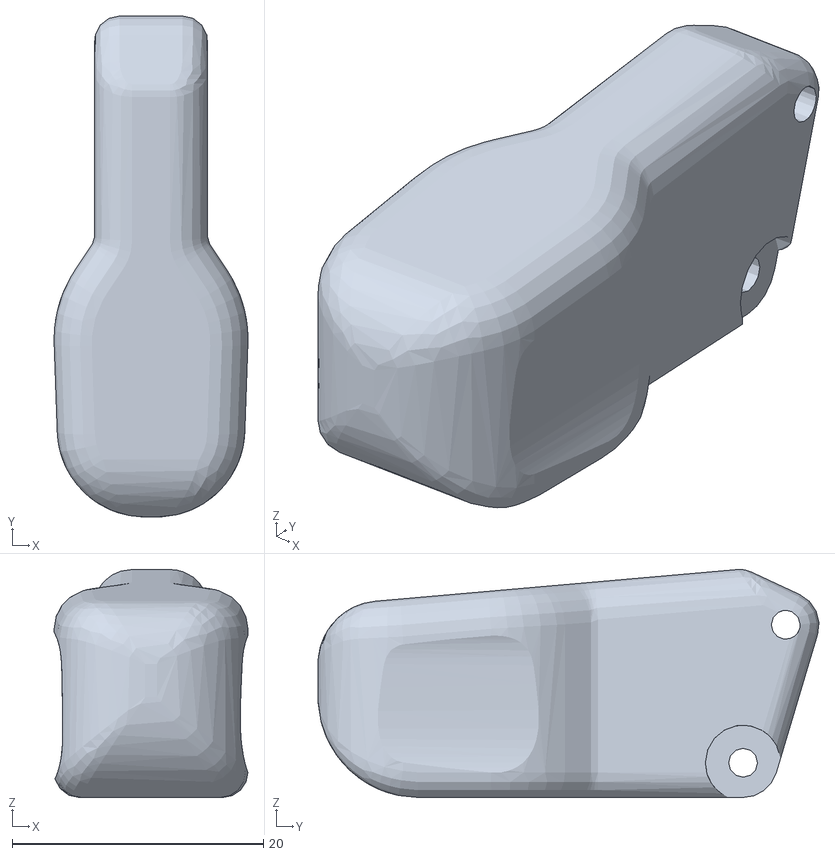
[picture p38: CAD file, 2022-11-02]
PARTS_SOLIDWORKS/finger assembly/distal_BA A.1.stl
15.4 x 39.9 x 18.2

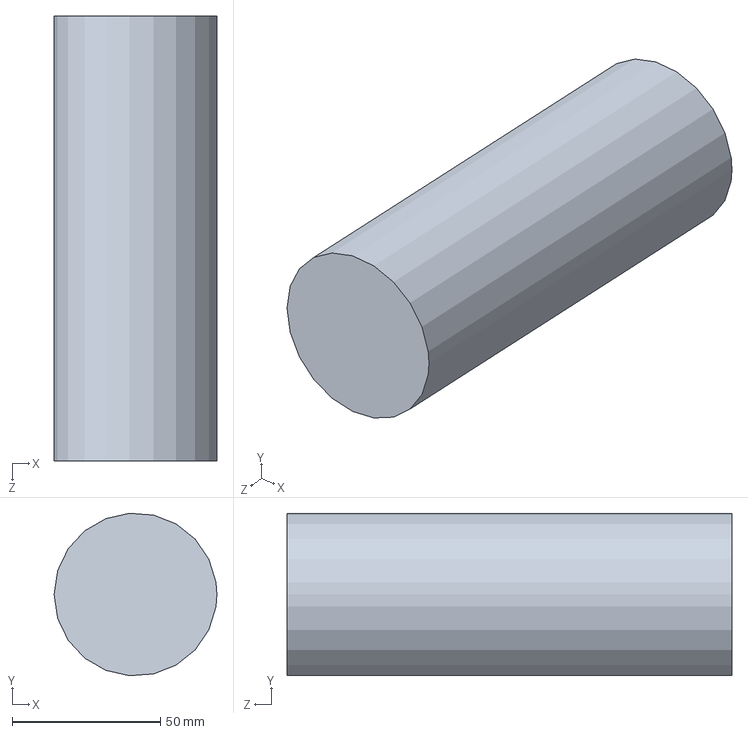
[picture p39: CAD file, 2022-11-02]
PARTS_SOLIDWORKS/damb.SLDPRT
54.9 x 54.7 x 150.0 mm

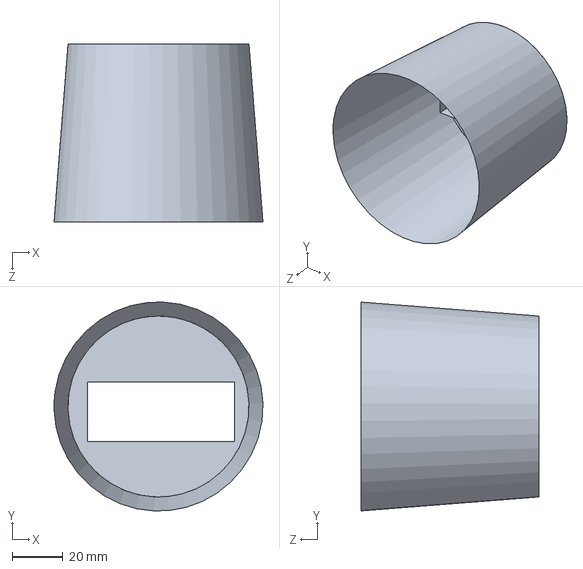
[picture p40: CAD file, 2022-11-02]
PARTS_SOLIDWORKS/coveringgggg.SLDPRT
82.0 x 81.9 x 70.0 mm

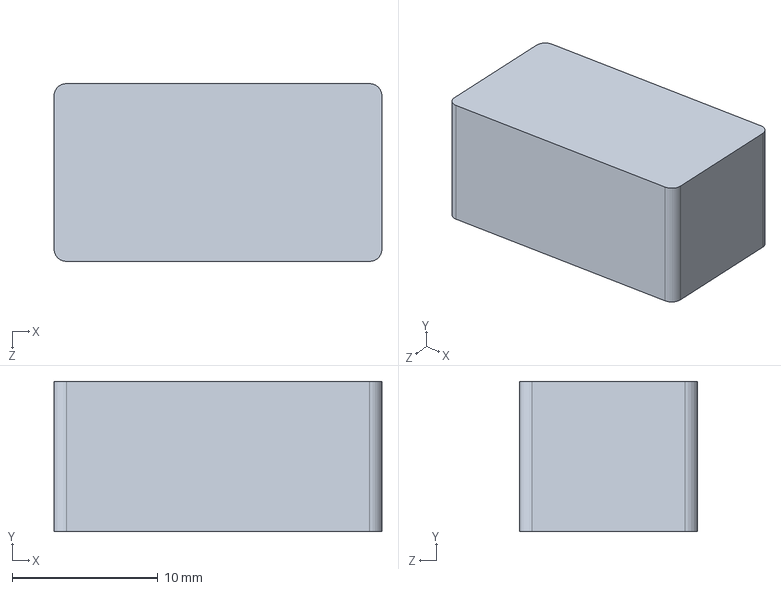
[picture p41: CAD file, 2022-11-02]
PARTS_SOLIDWORKS/ACT2.SLDPRT
22.5 x 10.3 x 12.2 mm

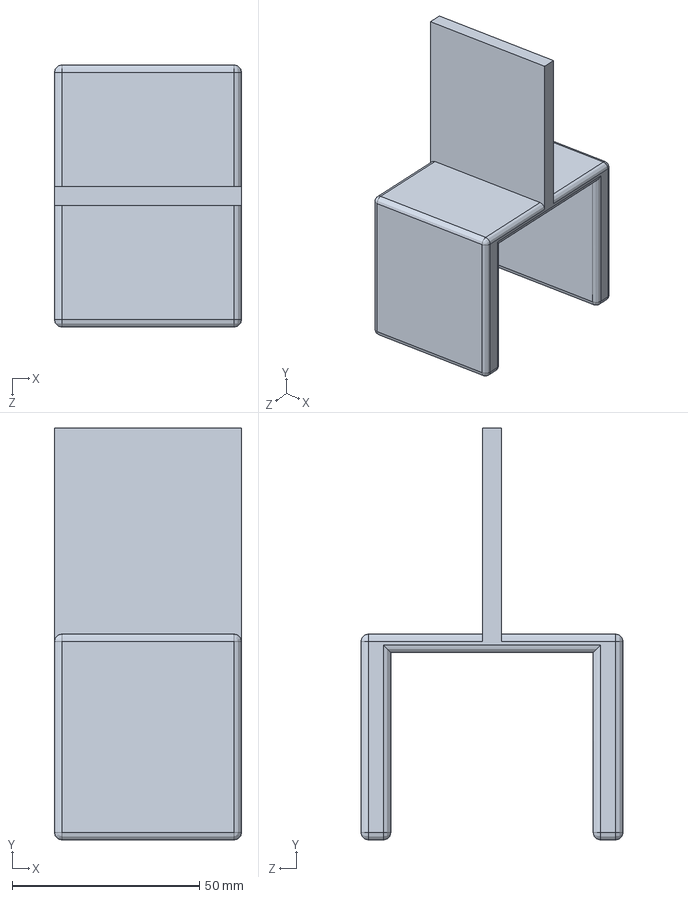
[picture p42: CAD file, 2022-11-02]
PARTS_SOLIDWORKS/trial4.SLDPRT
50.0 x 110.0 x 70.0 mm

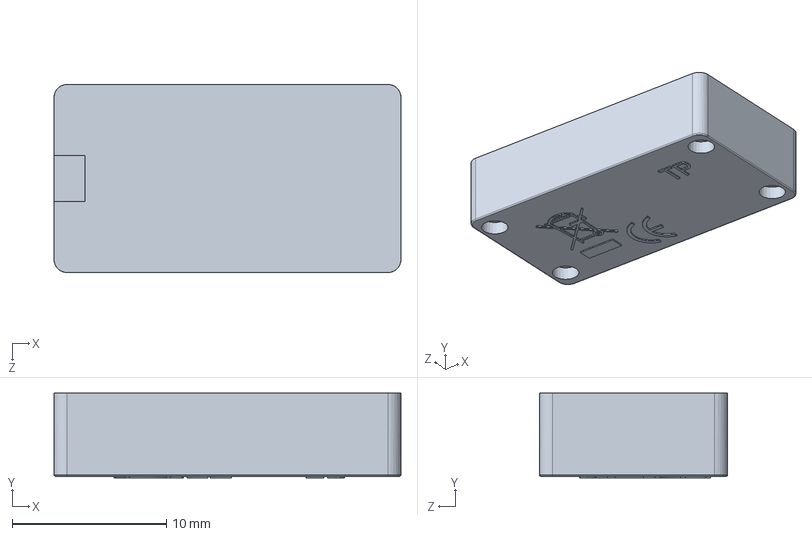
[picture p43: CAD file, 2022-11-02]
PARTS_SOLIDWORKS/ACT3.SLDPRT
22.5 x 5.50 x 12.2 mm

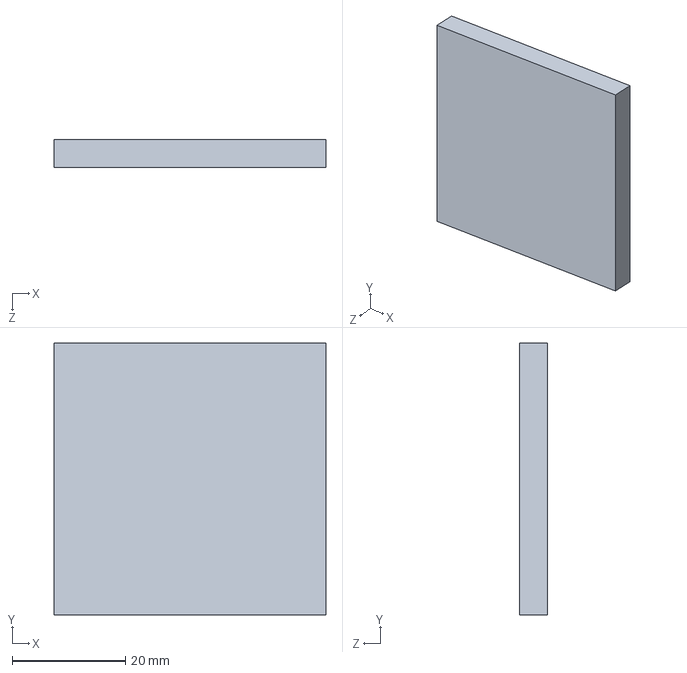
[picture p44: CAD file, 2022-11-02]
PARTS_SOLIDWORKS/square plate.SLDPRT
48.0 x 48.0 x 5.00 mm

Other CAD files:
PARTS_SOLIDWORKS/finger assembly/Final_Proximal_proo A.1.stl
PARTS_SOLIDWORKS/finger assembly/link_slider_BA A.1.stl
PARTS_SOLIDWORKS/ACT_STROKE.SLDPRT
PARTS_SOLIDWORKS/BODY.SLDPRT
PARTS_SOLIDWORKS/ACTUATOR_BODY.SLDPRT
PARTS_SOLIDWORKS/ACT_1.SLDPRT
PARTS_SOLIDWORKS/LINK2.SLDPRT
PARTS_SOLIDWORKS/MIDDLE.SLDPRT
PARTS_SOLIDWORKS/THUMB_BASE.SLDPRT
PARTS_SOLIDWORKS/TRIAL 3.SLDPRT
PARTS_SOLIDWORKS/TRIAL2.SLDPRT

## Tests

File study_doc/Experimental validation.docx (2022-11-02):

Experimental validation

1) Actuator 3 pin and 5 pin

Simple program

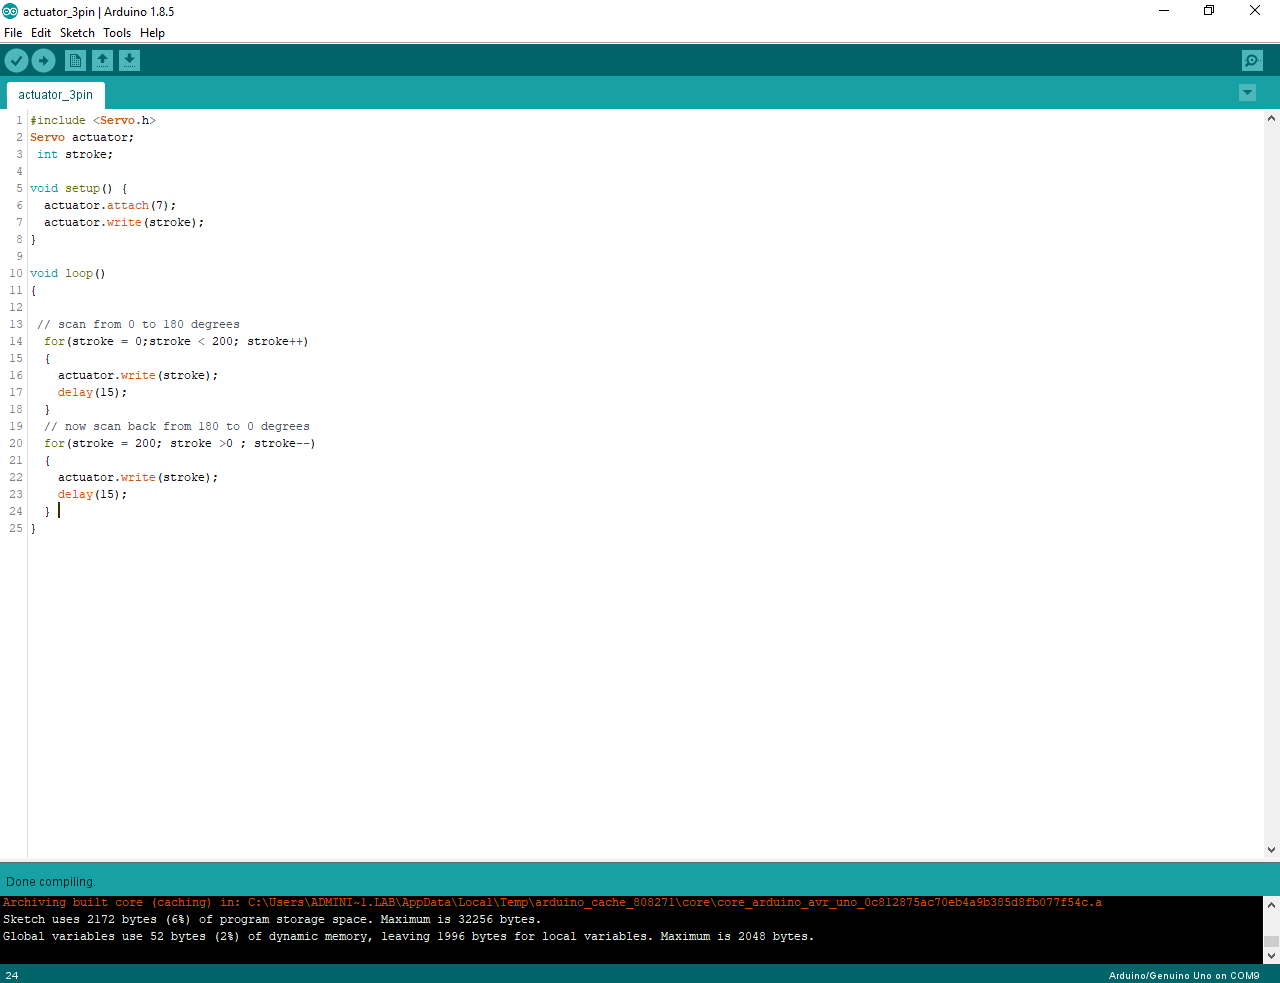
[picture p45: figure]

actuation

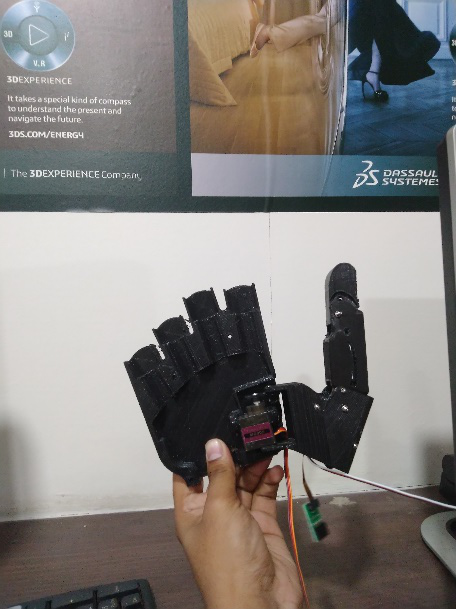
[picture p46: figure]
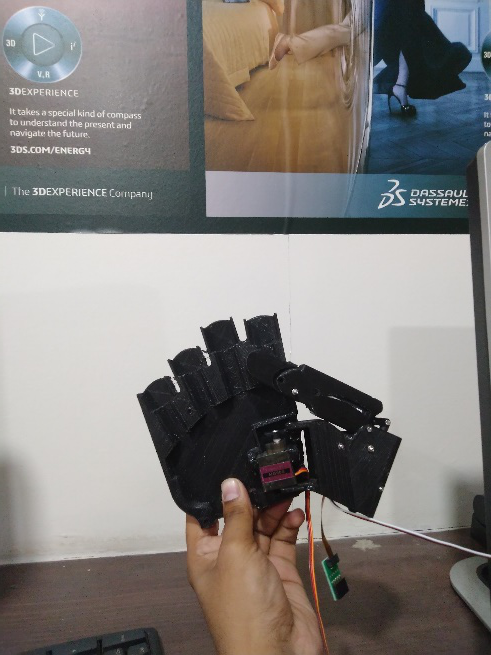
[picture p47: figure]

2) Servo mg995 micro servo and metal gear servo

Simple program

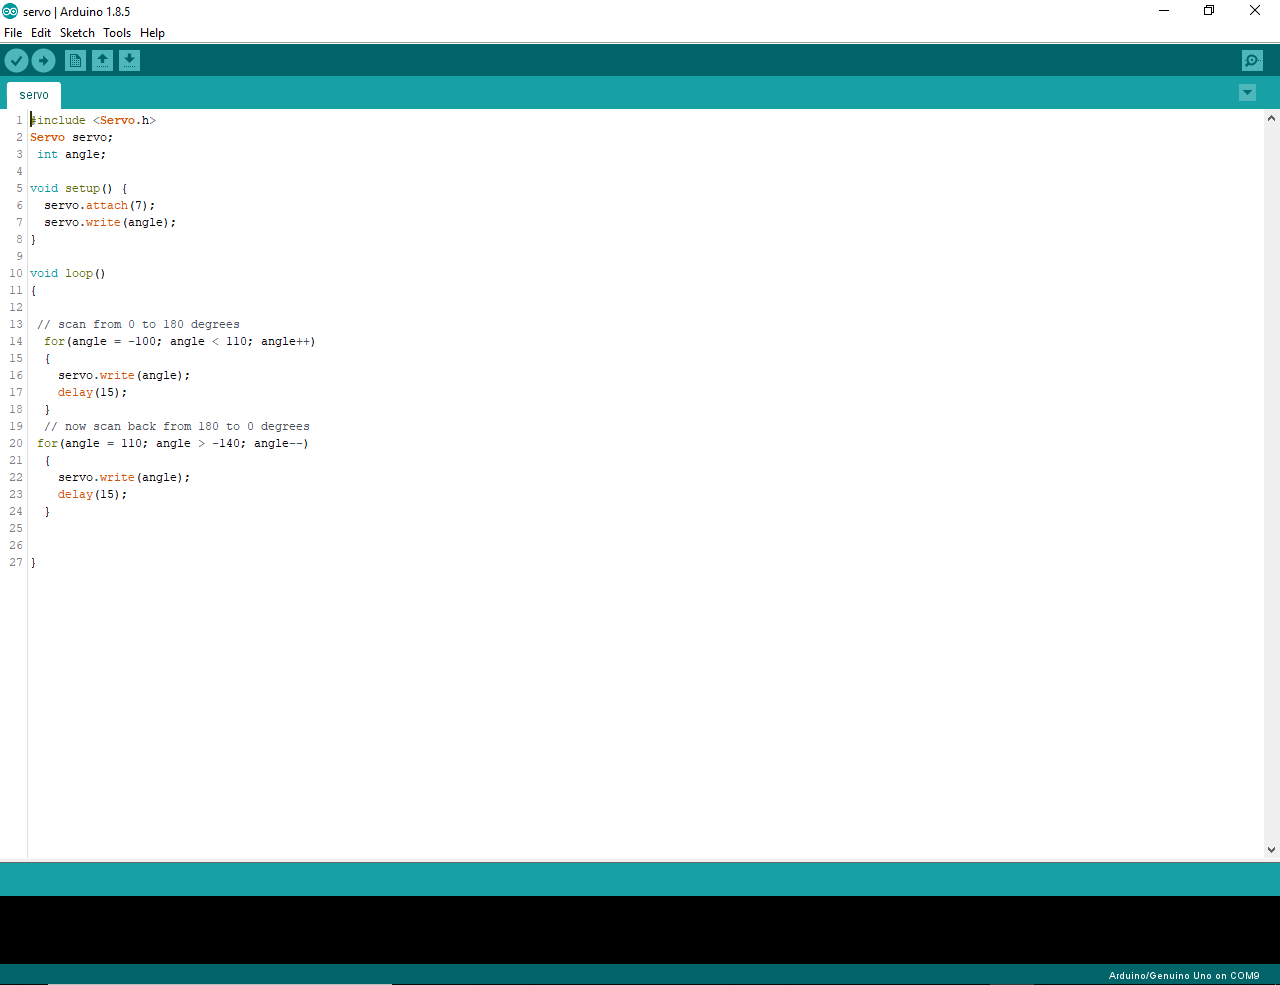
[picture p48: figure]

Actuation

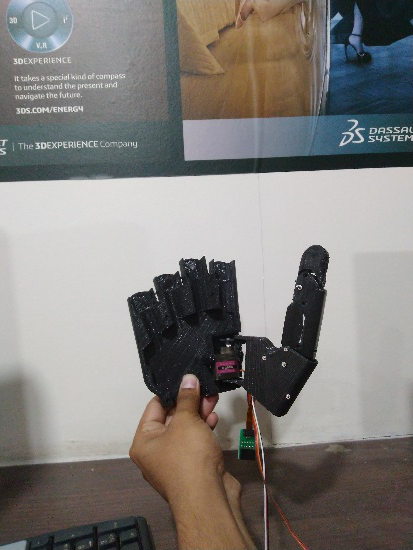
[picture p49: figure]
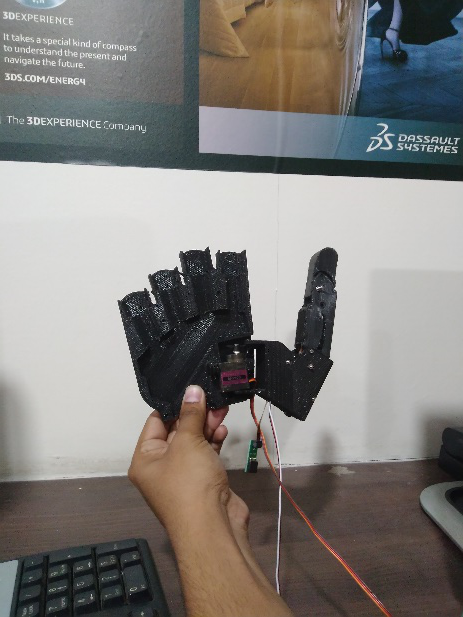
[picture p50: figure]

- FSR

Simple program

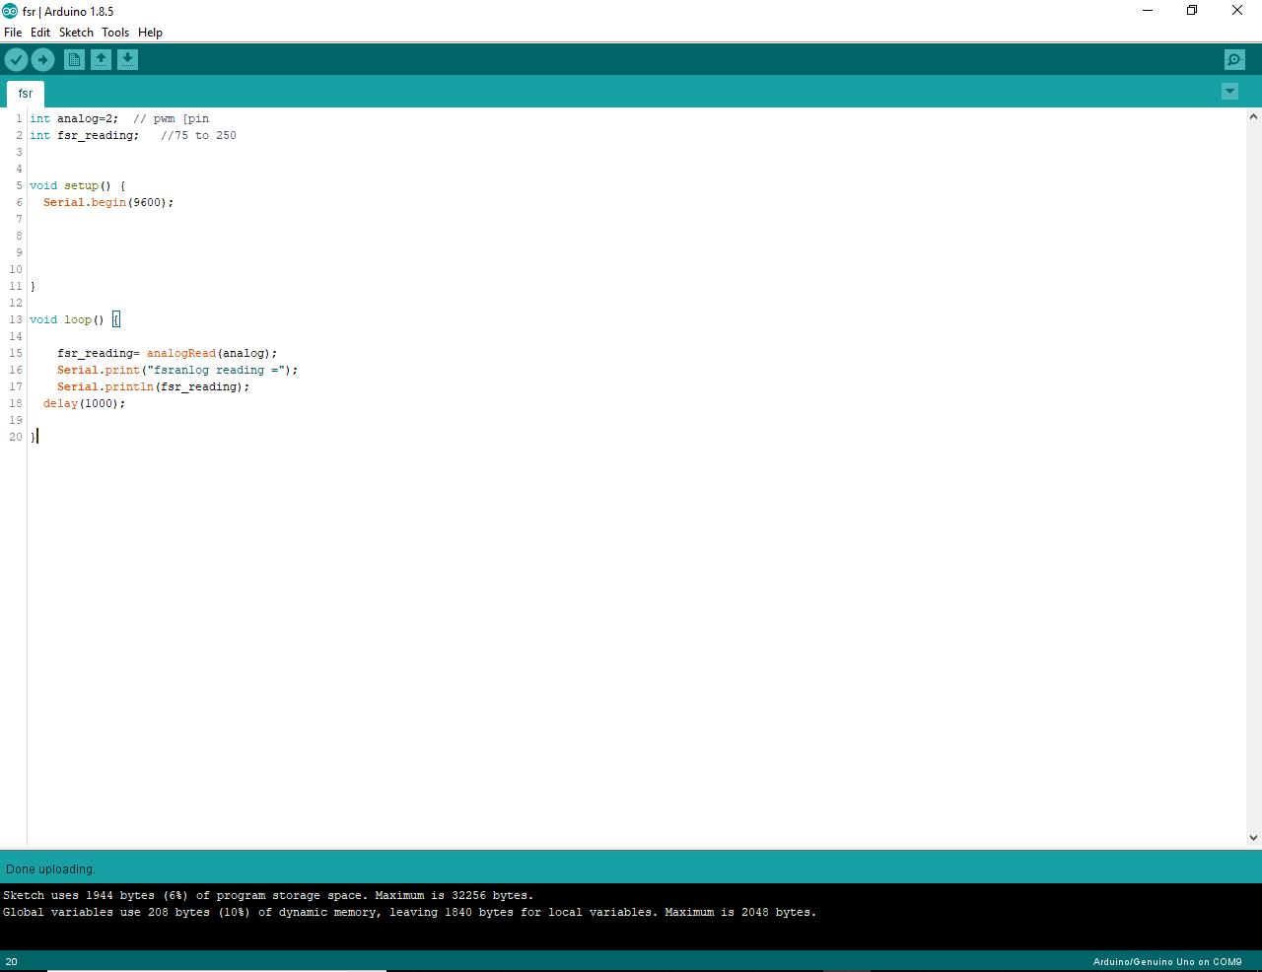
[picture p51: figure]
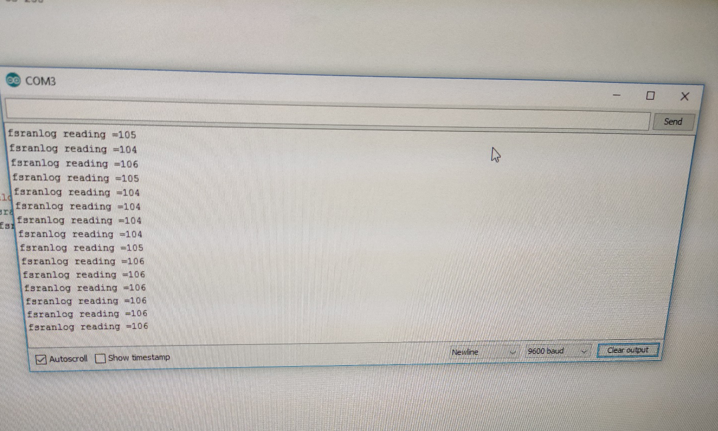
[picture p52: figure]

Serial monitor

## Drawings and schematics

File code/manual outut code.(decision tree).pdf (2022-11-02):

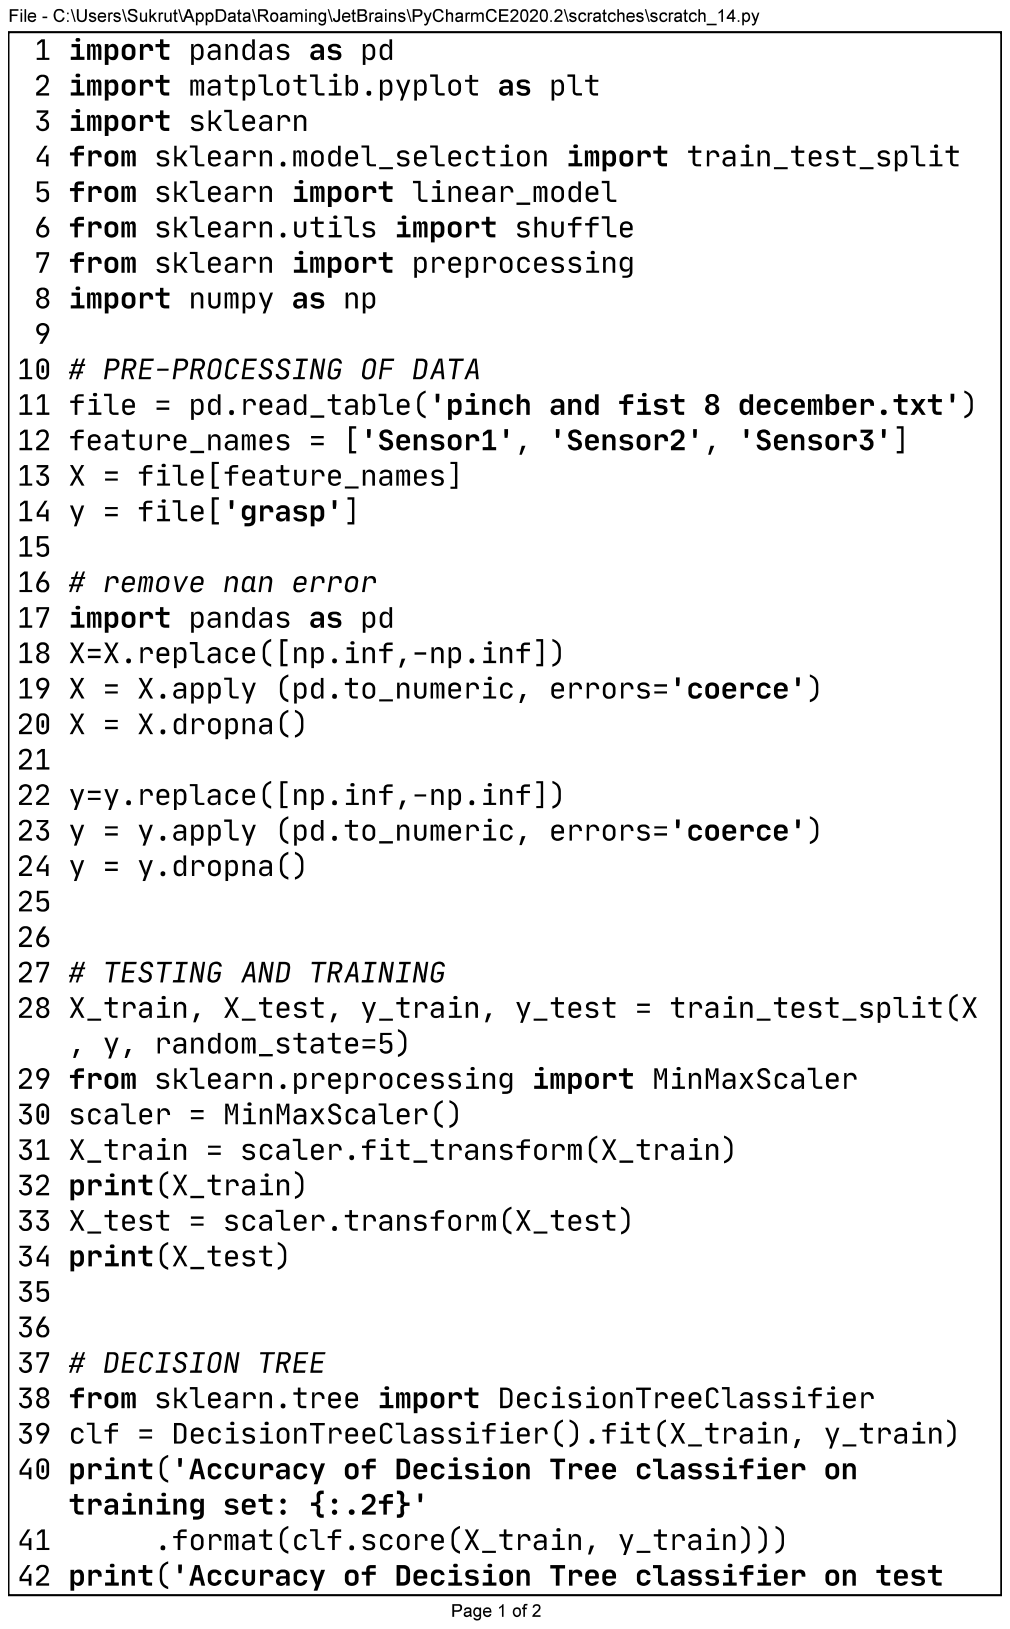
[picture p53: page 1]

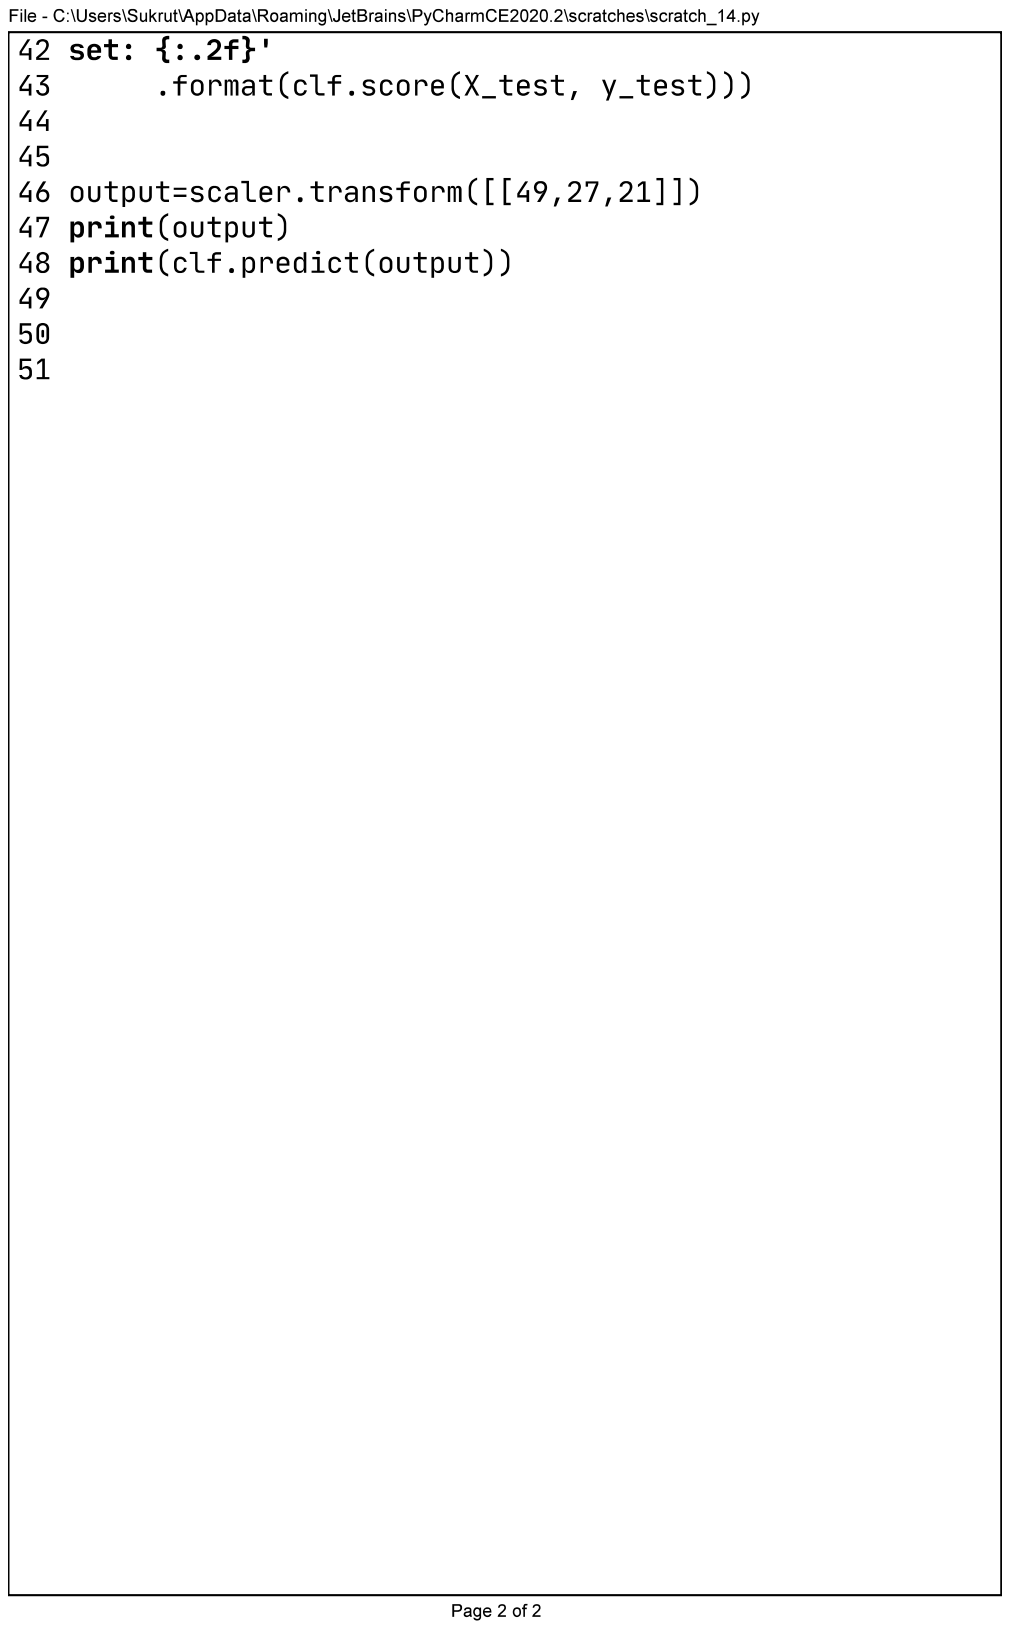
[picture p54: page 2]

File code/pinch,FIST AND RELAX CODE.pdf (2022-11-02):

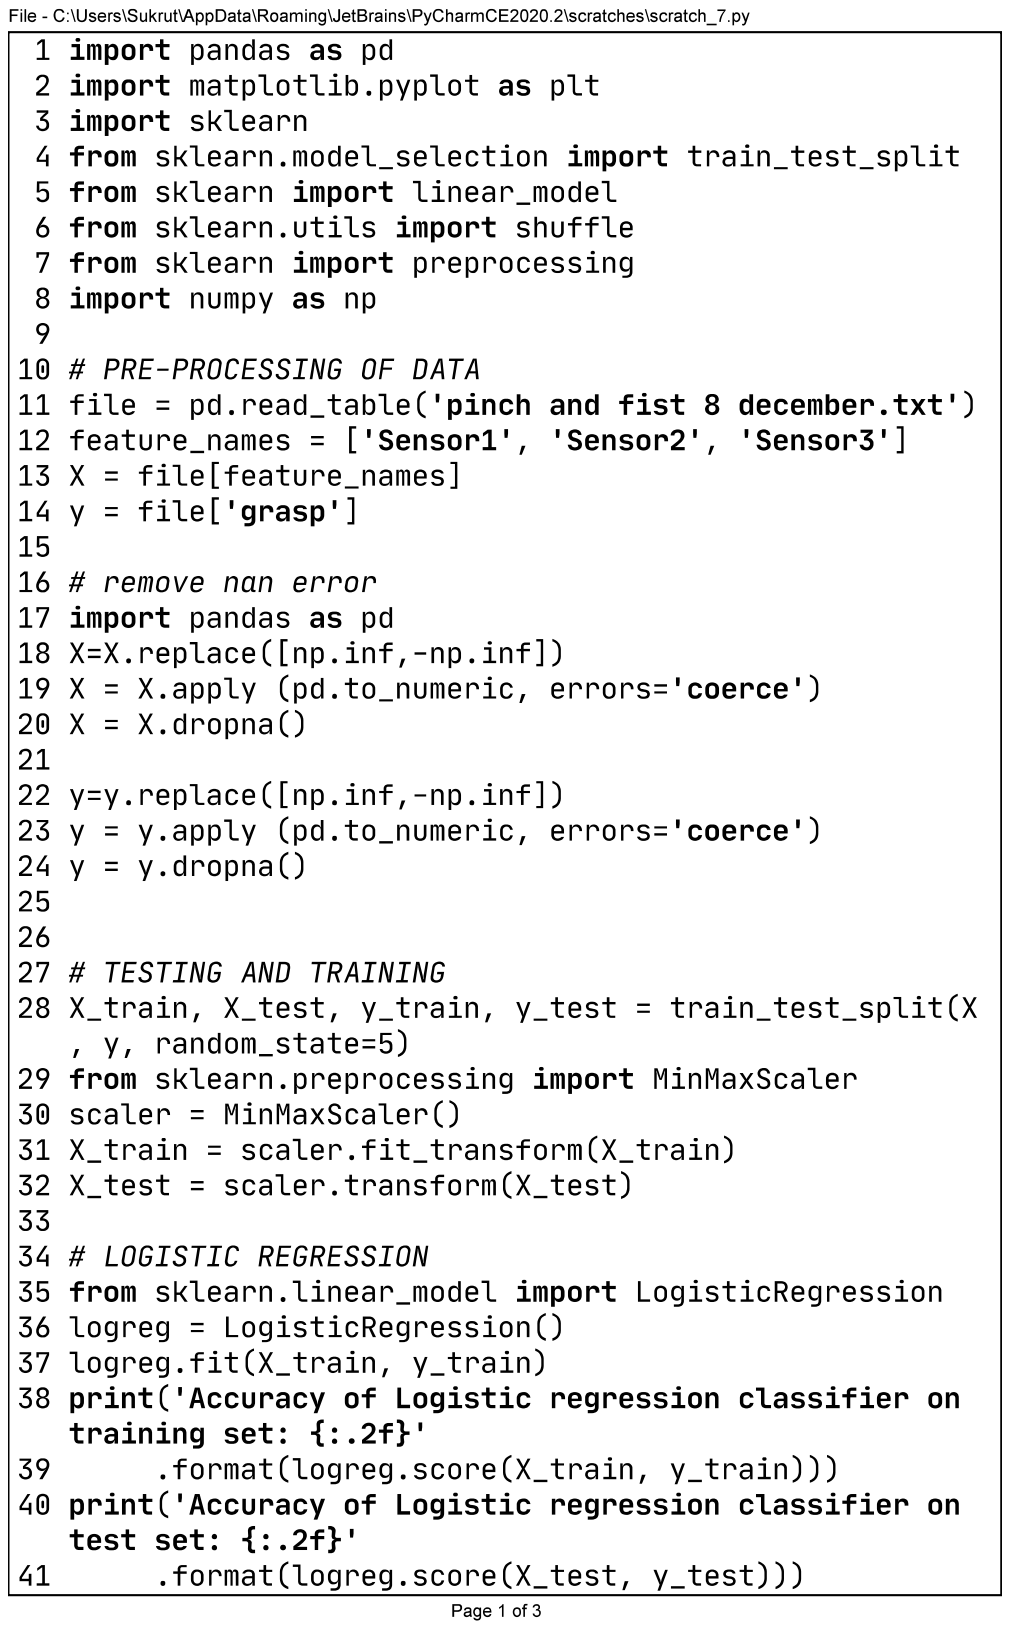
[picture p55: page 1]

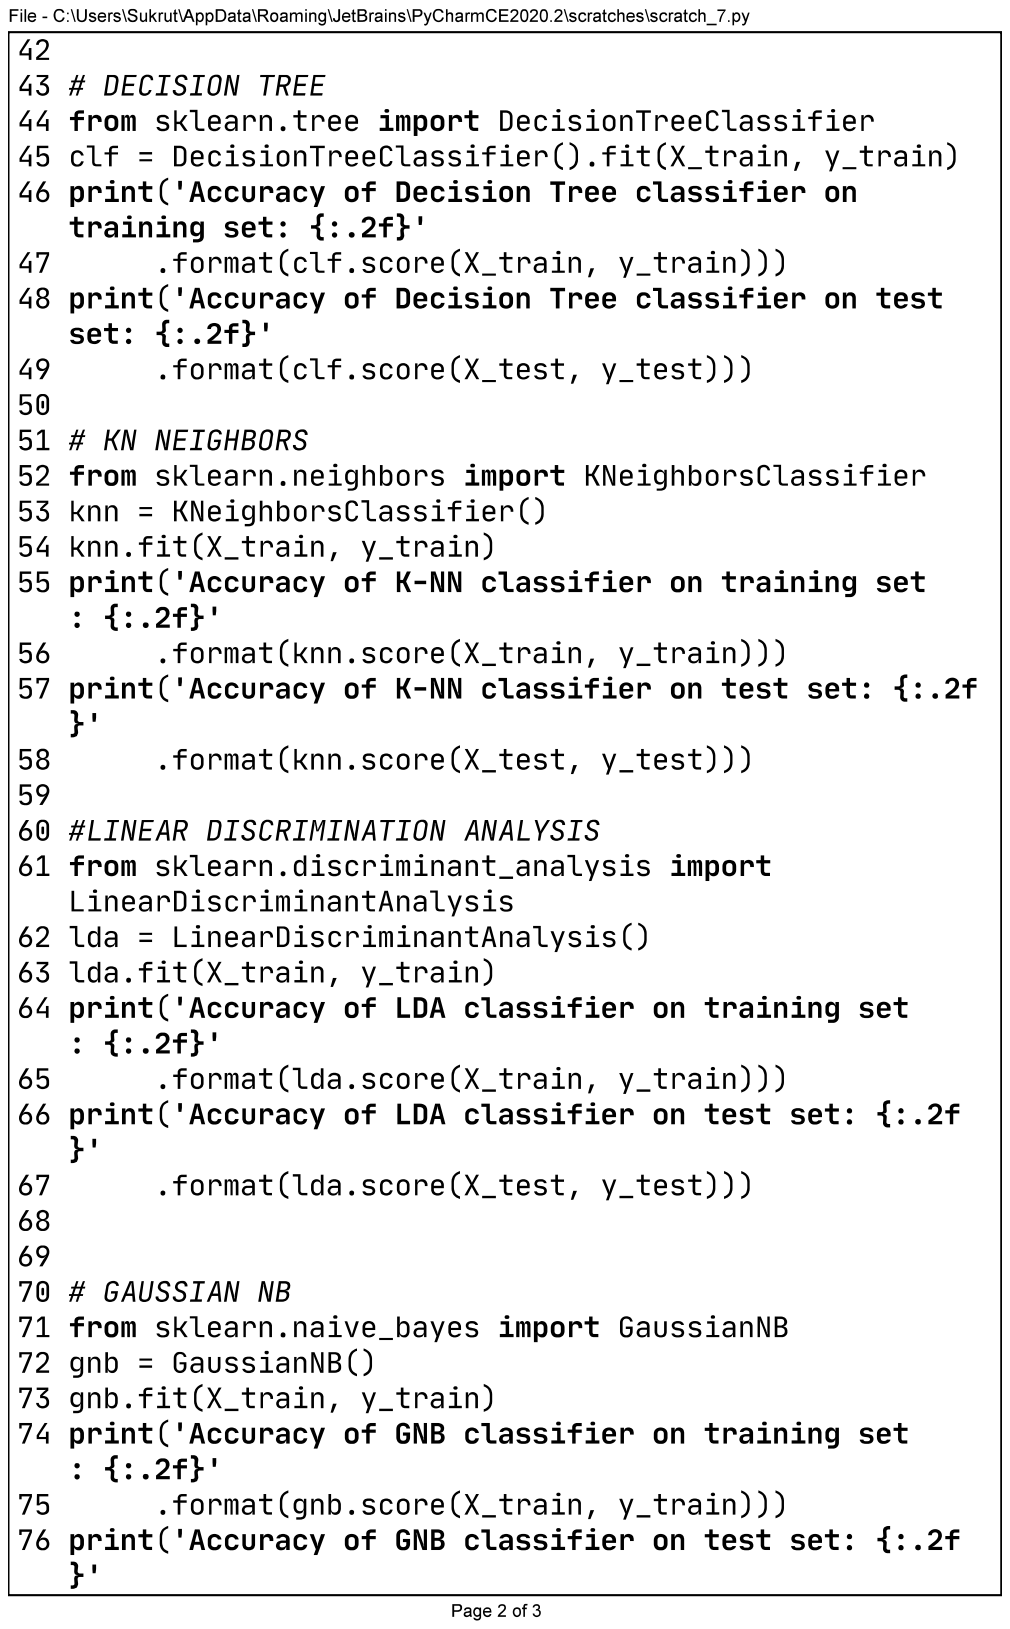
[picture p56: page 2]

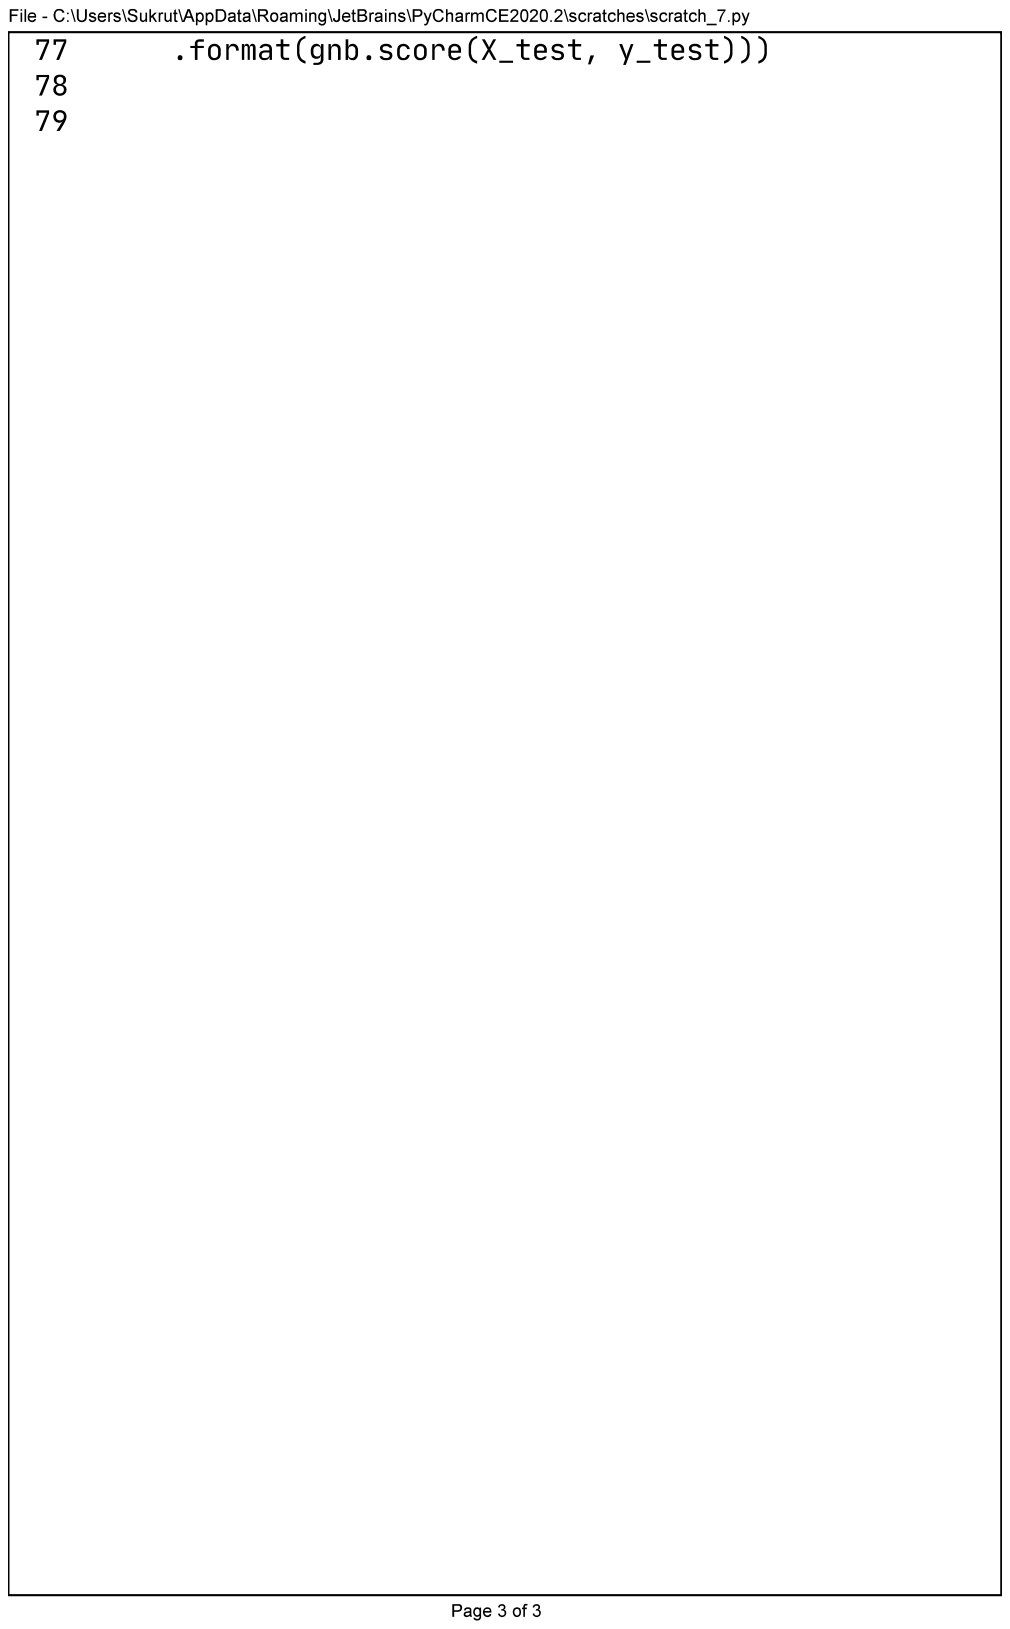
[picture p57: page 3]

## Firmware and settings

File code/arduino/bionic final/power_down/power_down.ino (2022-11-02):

 #include <Servo.h> 

Servo thumb2;
Servo middle2;
Servo ring2;
Servo little2;
//Servo thumb_pp;
int pos;
int thumb=2;//pq
int thumb_d=22;

int index=5;//pq
int index_d=26;
int index_u=4;//pq
int index_ud=24;
int middle=6;//pq
int middle_d=28;
 
int ring=7;//pq


int little=8;//pq

int little_ser=9;//pwm
int thumb_s=12;//pwm
int middle_ser=10;//pwm
int ring_ser=11;//pwm

#define in1 30
#define in2 32
#define in3 34
#define in4 36

void setup() {
  // put your setup code here, to run once:
pinMode(thumb, OUTPUT);
Serial.begin(9600);
pinMode(thumb_d, OUTPUT);
pinMode(thumb_s, OUTPUT);
pinMode(index_d, OUTPUT);
pinMode(index_u, OUTPUT);
pinMode(index_ud, OUTPUT);
pinMode(middle_d, OUTPUT);
pinMode(middle_ser, OUTPUT);
pinMode(ring, OUTPUT);
//pinMode(ring_d, OUTPUT);
pinMode(ring_ser, OUTPUT);
pinMode(little, OUTPUT);
//pinMode(little_d, OUTPUT);
//Serial.begin(9600);
pinMode(little_ser, OUTPUT);
thumb2.attach(12);
middle2.attach(10);
ring2.attach(11);
little2.attach(9);
//thumb_2.attach(12)
pinMode(in1, OUTPUT);
pinMode(in2, OUTPUT);
pinMode(in3, OUTPUT);
pinMode(in4, OUTPUT);
}

void loop() 
{
  
//digitalWrite(thumb_d,LOW);
digitalWrite(thumb_d,HIGH);
  ///
//digitalWrite(index_ud,LOW);
digitalWrite(index_ud,HIGH);
 ///
//digitalWrite(index_d,LOW);
digitalWrite(index_d,HIGH);
  ///
//digitalWrite(middle_d,LOW);
digitalWrite(middle_d,HIGH);
  ///


//HIGH RETRACT LOW UP(A+,B-)
analogWrite(thumb,250);
//
analogWrite(index_u,250);
//
analogWrite(index,250);
//
analogWrite(middle,250);
//

//

    //digitalWrite(in1, LOW);///UP
    //digitalWrite(in2, HIGH);///UP
   digitalWrite(in1, HIGH);///DOWN
    digitalWrite(in2, LOW);///DOWN
    analogWrite(ring,250);
    //
    //digitalWrite(in3, LOW);//UP
    //digitalWrite(in4, HIGH);//UP
    digitalWrite(in3, HIGH);//DOWN
    digitalWrite(in4, LOW);//DOWN
    analogWrite(little, 250);





thumb2.writeMicroseconds(2000);
middle2.writeMicroseconds(2000);
ring2.writeMicroseconds(2000);
little2.writeMicroseconds(2000);
while(1);
}

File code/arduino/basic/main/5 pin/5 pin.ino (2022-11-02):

int pwm =7;  // pwm [pin 
int pin=8;   //75 to 250


void setup() {
  pinMode(pwm,OUTPUT); 
  pinMode(pin,OUTPUT);


 
  
}

void loop() {
  
                               
     
                              
    digitalWrite(pwm,HIGH);  
  digitalWrite(pin,LOW);
                


}

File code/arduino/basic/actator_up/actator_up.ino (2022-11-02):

int thumb =2; //analog pin
int pwm = 9;  // pwm [pin
int dir =8;   // normal pin

void setup() {
  pinMode(thumb, OUTPUT);
  Serial.begin(9600);
  pinMode(pwm,OUTPUT); //md10c
  pinMode(dir,OUTPUT);  //md100

}

void loop() {
  int pwm_value=100;
  digitalWrite(dir,HIGH);      // clockwise rotation
    analogWrite(pwm,pwm_value);                                 
  analogWrite(thumb,10);
}
